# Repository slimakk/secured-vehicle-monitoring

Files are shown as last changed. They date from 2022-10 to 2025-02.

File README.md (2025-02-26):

# SECURED VEHICLE MONITORING USING OBDII AND LPWAN NETWORKS

This repository contains hardware design files and source code for bachelor thesis at FEEC BUT, which was sucessfully defended in 2023. The main goal behind the creation of this thesis was to create a device that would be capable of reporting important engine parameters to an external server for further processing.

[Link to a full thesis](https://www.vut.cz/studenti/zav-prace?zp_id=151037)
---------------------------------------------------------------------------
## Hardware specs
* MCU -- STM32 L431
* LPWAN module -- Quectel BG77, supports NB-IoT, LTE Cat M, GPS
* Power -- Synchronous Step-Down Converter by Texas Instruments
* Vehicle comms -- CAN Bus, K-Line, KWP2000
## Software
* OBD II support -- only mode 02
* Data transmission -- UDP, TCP, MQTT

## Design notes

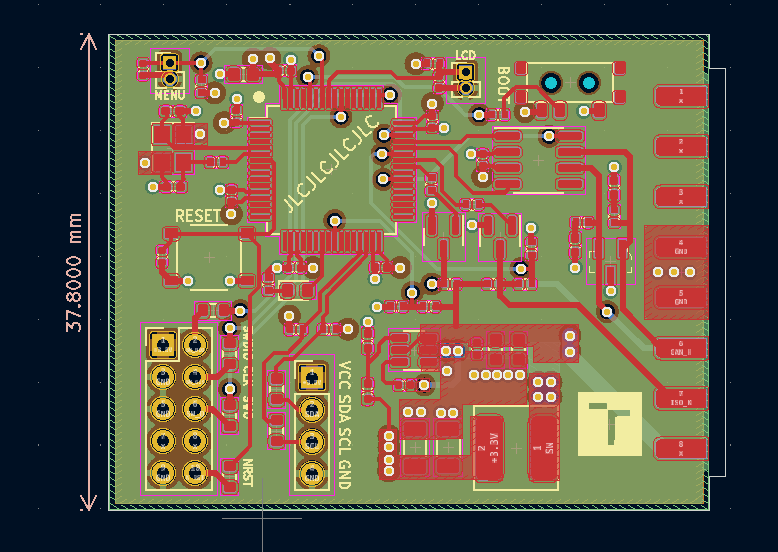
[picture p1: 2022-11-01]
Images/board.png

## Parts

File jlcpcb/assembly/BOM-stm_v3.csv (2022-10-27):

Comment | Designator | Footprint | LCSC
10k | R15,R4 | R_0402_1005Metric | C11616
SN65HVD231 | U2 | SOIC-8_3.9x4.9mm_P1.27mm | C129257
16 MHz | Y1 | Crystal_SMD_3225-4Pin_3.2x2.5mm | C13738
100n | C10,C11,C17,C2,C20,C21,C3,C4,C5,C6,C7 | C_0402_1005Metric | C1525
0R | R3 | R_0402_1005Metric | C17168
4u7 | C1 | C_0603_1608Metric | C19666
s8050 | Q1,Q2 | SOT-23 | C2146
22R | R10,R5,R6,R7,R8,R9 | R_0603_1608Metric | C23345
100R | R1,R2 | R_0402_1005Metric | C25076
510R | R16,R17 | R_0402_1005Metric | C25123
100k | R20,R22 | R_0402_1005Metric | C25741
27k | R21,R23 | R_0402_1005Metric | C25771
2k2 | R18,R19 | R_0402_1005Metric | C25879
4k7 | R11,R12,R24,R25 | R_0402_1005Metric | C25900
100n | C16 | C_0402_1005Metric | C307331
RST | SW1 | XKB_TS_1187A | C318884
BOOT0 | SW2 | XKB_SS-3292S | C397350
22u | C18,C19 | C_1206_3216Metric | C5672
LED | D2 | LED_0603_1608Metric | C72038
PESD2CAN_215 | D1 | SOT-23-3 | C75176
TPS562201 | U3 | SOT-23-6 | C90061
STM32L431RCTx | U1 | LQFP-64_10x10mm_P0.5mm | C92468
10u | C14,C15 | C_0603_1608Metric | C96446

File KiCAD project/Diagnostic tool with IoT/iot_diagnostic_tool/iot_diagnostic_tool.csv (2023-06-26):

Source: | C:\Users\miros\Desktop\bakalarka_latest\secured-vehicle-monitoring\KiCAD project\Diagnostic tool with IoT\iot_diagnostic_tool\iot_diagnostic_tool.kicad_sch
Date: | 5/17/2023 1:02:22 PM
Tool: | Eeschema (7.0.0)
Generator: | C:\Program Files\KiCad\6.0\bin\scripting\plugins/bom_csv_grouped_by_value_with_fp.py
Component Count: | 108
Ref | Qnty | Value | Cmp name | Footprint | Description | Vendor
AE1, | 1 | IoT_ANT | Antenna | Connector_Coaxial:U.FL_Hirose_U.FL-R-SMT-1_Vertical | Antenna
AE2, | 1 | GNSS_ANT | Antenna | Connector_Coaxial:U.FL_Hirose_U.FL-R-SMT-1_Vertical | Antenna
C1, | 1 | 4u7 | C | Capacitor_SMD:C_0603_1608Metric | Unpolarized capacitor
C2, C3, C4, C5, C6, C7, C8, C11, C14, C18, C23, C36, | 12 | 100n | C | Capacitor_SMD:C_0402_1005Metric | Unpolarized capacitor
C9, C10, | 2 | 8p | C | Capacitor_SMD:C_0402_1005Metric_Pad0.74x0.62mm_HandSolder | Unpolarized capacitor
C12, C13, | 2 | 10u | C | Capacitor_SMD:C_0603_1608Metric | Unpolarized capacitor
C15, C16, C17, | 3 | 22u | C | Capacitor_SMD:C_0805_2012Metric | Unpolarized capacitor
C19, C20, | 2 | 560p | C | Capacitor_SMD:C_0402_1005Metric_Pad0.74x0.62mm_HandSolder | Unpolarized capacitor
C21, | 1 | 10p | C | Capacitor_SMD:C_0402_1005Metric | Unpolarized capacitor
C22, | 1 | 33p | C | Capacitor_SMD:C_0402_1005Metric | Unpolarized capacitor
C24, | 1 | 100u | C_Polarized | Capacitor_Tantalum_SMD:CP_EIA-3528-21_Kemet-B | Polarized capacitor
C25, C37, | 2 | 10n | C | Capacitor_SMD:C_0402_1005Metric | Unpolarized capacitor
C27, C32, | 2 | 100n | C | Capacitor_SMD:C_0402_1005Metric_Pad0.74x0.62mm_HandSolder | Unpolarized capacitor
C28, C29, | 2 | 1u | C | Capacitor_SMD:C_0603_1608Metric | Unpolarized capacitor
C33, C34, C35, | 3 | 33p | C | Capacitor_SMD:C_0402_1005Metric_Pad0.74x0.62mm_HandSolder | Unpolarized capacitor
C38, C39, C40, C41, | 4 | NM | C | Capacitor_SMD:C_0402_1005Metric | Unpolarized capacitor
D1, | 1 | PESD2CAN | PESD2CAN | Package_TO_SOT_SMD:SOT-23 | SOT-23 Dual bidirectional TVS diode for CAN bus protection, 24V, 230W, Alternate KiCAD Library
D2, | 1 | LED | LED | Diode_SMD:D_0603_1608Metric | Light emitting diode
D5, | 1 | PESD5V0L5UY | PESD5V0L5UY | Package_TO_SOT_SMD:SOT-363_SC-70-6_Handsoldering | SOT-363 TVS Diode array, 5xUnidirectional, 5V, 25W, Alternate KiCAD Library
D6, D11, | 2 | TPSMF4L5.0A | TPSMF4L5.0A | Diode_SMD:D_SOD-123F | SOD-123F Unidirectional TVS diode, 5V, 400W, Alternate KiCAD Library
D7, | 1 | PESD5V0X1BT,215 | PESD5V2S2UT | Package_TO_SOT_SMD:SOT-23 | SOT-23 Dual Unidirectional TVS Diode, can be used as 1xBidirectional, 5.2V, 260W, Alternate KiCAD Library
D8, D9, D10, | 3 | ESD9L3.3 | ESD9L3.3 | Diode_SMD:D_SOD-923 | SOD-923 Unidirectional TVS diode, 3.3V, Alternate KiCAD Library
F1, | 1 | 2A | Fuse | Fuse:Fuse_0603_1608Metric_Pad1.05x0.95mm_HandSolder | Fuse
J2, | 1 | USB | Conn_02x04_Odd_Even | Connector_PinHeader_2.54mm:PinHeader_2x04_P2.54mm_Vertical_SMD | Generic connector, double row, 02x04, odd/even pin numbering scheme (row 1 odd numbers, row 2 even numbers), script generated (kicad-library-utils/schlib/autogen/connector/)
J3, | 1 | 693023010811 | 693023010811 | 693023010811:693023010811
J5, | 1 | Debug | Conn_02x05_Odd_Even | Connector_PinHeader_2.54mm:PinHeader_2x05_P2.54mm_Vertical | Generic connector, double row, 02x05, odd/even pin numbering scheme (row 1 odd numbers, row 2 even numbers), script generated (kicad-library-utils/schlib/autogen/connector/)
J6, | 1 | BOOT | Conn_01x03_Pin | Connector_PinHeader_2.54mm:PinHeader_1x03_P2.54mm_Vertical | Generic connector, single row, 01x03, script generated
J7, | 1 | OBD | 436500827 | 436500827:MOLEX_436500827
L1, | 1 | 3u3 | L | tme_library:VLS6045AF | Inductor
Q1, Q2, Q4, | 3 | BC817 | BC817 | Package_TO_SOT_SMD:SOT-23 | NPN SOT-23 transistor, 45V, 500mA, 250mW, Complementary to BC807, Alternate KiCAD Library
Q3, Q5, | 2 | BC817 | BC817 | Package_TO_SOT_SMD:SOT-23_Handsoldering | NPN SOT-23 transistor, 45V, 500mA, 250mW, Complementary to BC807, Alternate KiCAD Library
Q6, | 1 | RUM001L02T2CL | Q_NMOS_GSD | Package_TO_SOT_SMD:SOT-723 | N-MOSFET transistor, gate/source/drain
R1, R34, R37, | 3 | 10k | R | Resistor_SMD:R_0402_1005Metric | Resistor
R2, | 1 | 33k2 | R | Resistor_SMD:R_0402_1005Metric_Pad0.72x0.64mm_HandSolder | Resistor
R3, R40, R41, R44, R45, | 5 | 10k | R | Resistor_SMD:R_0402_1005Metric_Pad0.72x0.64mm_HandSolder | Resistor
R4, R5, | 2 | 100R | R | Resistor_SMD:R_0402_1005Metric | Resistor
R6, R8, R17, | 3 | 2k2 | R | Resistor_SMD:R_0402_1005Metric | Resistor
R7, R9, | 2 | 510R | R | Resistor_SMD:R_0402_1005Metric | Resistor
R10, R12, | 2 | 100k | R | Resistor_SMD:R_0402_1005Metric | Resistor
R11, R13, | 2 | 27k | R | Resistor_SMD:R_0402_1005Metric | Resistor
R14, R18, | 2 | 4k7 | R | Resistor_SMD:R_0402_1005Metric | Resistor
R15, R19, | 2 | 47k | R | Resistor_SMD:R_0402_1005Metric | Resistor
R16, | 1 | 200k | R | Resistor_SMD:R_0402_1005Metric_Pad0.72x0.64mm_HandSolder | Resistor
R28, R29, R30, R35, R36, R38, R39, | 7 | 0R | R | Resistor_SMD:R_0402_1005Metric | Resistor
R31, | 1 | 51k | R | Resistor_SMD:R_0402_1005Metric | Resistor
R32, | 1 | 15k | R | Resistor_SMD:R_0402_1005Metric | Resistor
R33, | 1 | 20k | R | Resistor_SMD:R_0402_1005Metric | Resistor
R42, R43, | 2 | 100k | R | Resistor_SMD:R_0402_1005Metric_Pad0.72x0.64mm_HandSolder | Resistor
SW1, | 1 | RST | SW_Push | tme_library:XKB_TS_1187A | Push button switch, generic, two pins
SW3, | 1 | IoT_RST | SW_Push | tme_library:XKB_TS_1187A | Push button switch, generic, two pins
U1, | 1 | STM32L431RCTx | STM32L431RCTx | Package_QFP:LQFP-64_10x10mm_P0.5mm | STMicroelectronics Arm Cortex-M4 MCU, 256KB flash, 64KB RAM, 80 MHz, 1.71-3.6V, 52 GPIO, LQFP64
U2, | 1 | TPS562201 | TPS562201 | Package_TO_SOT_SMD:SOT-23-6
U3, | 1 | SN65HVD231 | SN65HVD231 | Package_SO:SOIC-8_3.9x4.9mm_P1.27mm | CAN Bus Transceivers, 3.3V, 1Mbps,Ultra Low-Power capabilities, SOIC-8
U4, | 1 | BG77LA-64-SGNS | BG77LA-64-SGNS | BG77LA-64-SGNS:MODULE_BG77LA-64-SGNS
U6, | 1 | AP2120N-1.8 | AP2127N-1.8 | Package_TO_SOT_SMD:SOT-23_Handsoldering | 300mA low dropout linear regulator, shutdown pin, 2.5V-6V input voltage, 1.8V fixed positive output, SOT-23 package
U8, | 1 | NVT2010 | NVT2010 | Package_SO:TSSOP-24_4.4x7.8mm_P0.65mm | Bidirectional voltage-level translator for open-drain and push-pull applications
Y1, | 1 | 16 MHz | Crystal_GND24 | Crystal:Crystal_SMD_3225-4Pin_3.2x2.5mm | Four pin crystal, GND on pins 2 and 4

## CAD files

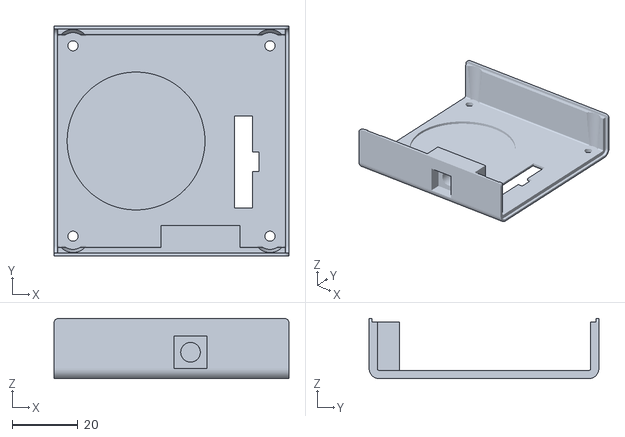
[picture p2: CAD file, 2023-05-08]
Case/IoT_OBD_tool/top.stl
71.6 x 70.0 x 18.3

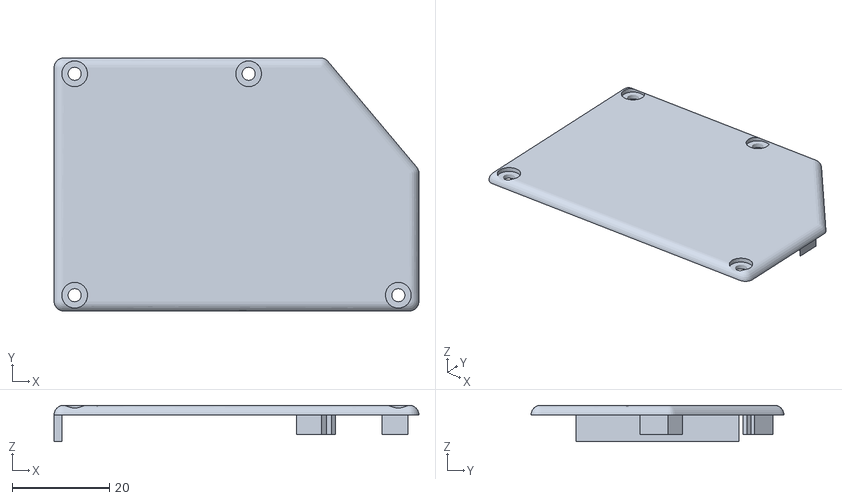
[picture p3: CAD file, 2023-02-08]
Case/OBD_tool/top_v2.stl
75.0 x 52.0 x 7.50

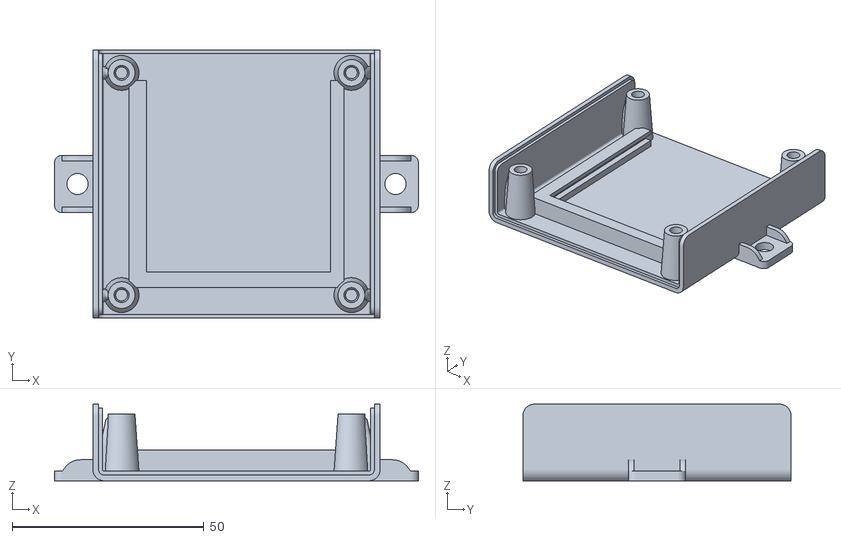
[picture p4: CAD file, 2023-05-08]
Case/IoT_OBD_tool/base.stl
95.0 x 70.0 x 20.0

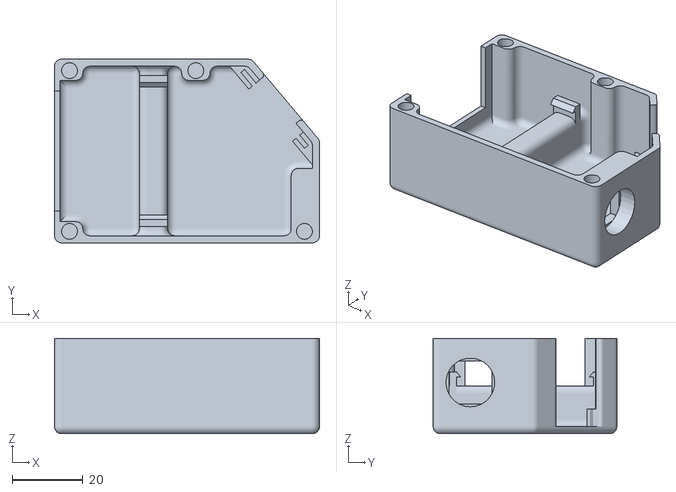
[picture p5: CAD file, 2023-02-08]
Case/OBD_tool/base_v2.stl
75.0 x 52.0 x 27.0

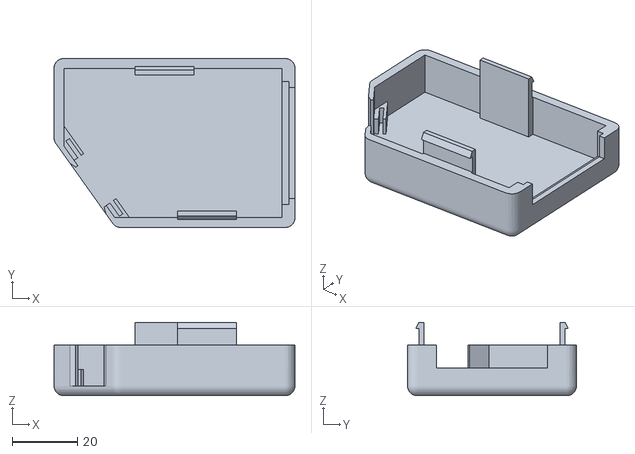
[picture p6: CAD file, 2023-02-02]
Case/OBD_tool/base_mir1.stl
73.9 x 51.8 x 22.5

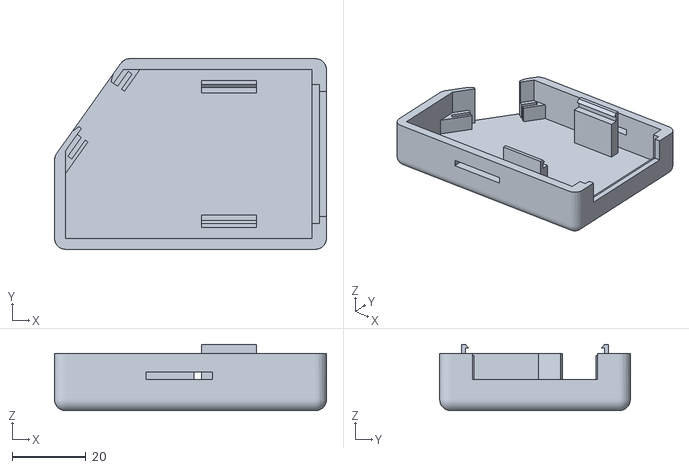
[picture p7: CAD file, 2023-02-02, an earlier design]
Case/OBD_tool/base.stl
73.9 x 51.8 x 18.0

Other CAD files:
Case/IoT_OBD_tool/base_v2.stl
Case/IoT_OBD_tool/base.ipt
Case/IoT_OBD_tool/case.iam
Case/IoT_OBD_tool/iot_diagnostic_tool.iam
Case/IoT_OBD_tool/iot_diagnostic_tool/436500827.iam
Case/IoT_OBD_tool/iot_diagnostic_tool/693023010811.iam
Case/IoT_OBD_tool/iot_diagnostic_tool/BG77LATEA-64-SGNS.iam
Case/IoT_OBD_tool/iot_diagnostic_tool/COMPOUND.ipt
Case/IoT_OBD_tool/iot_diagnostic_tool/COMPOUND_1.ipt
Case/IoT_OBD_tool/iot_diagnostic_tool/COMPOUND_2.ipt
Case/IoT_OBD_tool/iot_diagnostic_tool/COMPOUND_3.ipt
Case/IoT_OBD_tool/iot_diagnostic_tool/CP_EIA-3528-21_Kemet-B.iam
Case/IoT_OBD_tool/iot_diagnostic_tool/C_0402_1005Metric.iam
Case/IoT_OBD_tool/iot_diagnostic_tool/C_0603_1608Metric.iam
Case/IoT_OBD_tool/iot_diagnostic_tool/C_0805_2012Metric.iam
Case/IoT_OBD_tool/iot_diagnostic_tool/Crystal_SMD_3225-4Pin_3.2x2.5mm.iam
Case/IoT_OBD_tool/iot_diagnostic_tool/D_0603_1608Metric.iam
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

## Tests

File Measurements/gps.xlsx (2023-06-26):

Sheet: 2023-06-09_14_13_influxdb_data
Column6 | Column7 | Column8
false | false | true
dateTime:RFC3339 | double | string
_time | _value | _field
2023-05-21T14:39:20Z | 4913.9652 | lat
2023-05-21T14:39:25Z | 4913.9652 | lat
2023-05-21T14:39:50Z | 4913.9652 | lat
2023-05-21T14:40:05Z | 4913.9635 | lat
2023-05-21T14:40:15Z | 4913.9636 | lat
2023-05-21T14:40:30Z | 4913.9636 | lat
2023-05-21T14:40:45Z | 4913.9636 | lat
2023-05-21T14:40:50Z | 4913.9556 | lat
2023-05-21T14:41:00Z | 4913.9556 | lat
2023-05-21T14:41:25Z | 4913.9593 | lat
2023-05-21T14:41:45Z | 4913.9627 | lat
2023-05-21T14:41:50Z | 4913.9627 | lat
2023-05-21T14:42:00Z | 4913.9611 | lat
2023-05-21T14:42:30Z | 4913.9608 | lat
2023-05-21T14:42:35Z | 4913.97 | lat
2023-05-21T14:42:45Z | 4913.9694 | lat
2023-05-21T14:42:55Z | 4913.9694 | lat
2023-05-21T14:43:05Z | 4913.9694 | lat
2023-05-21T14:43:15Z | 4913.9764 | lat
2023-05-21T14:43:25Z | 4913.9718 | lat
2023-05-21T14:43:40Z | 4913.9718 | lat
2023-05-21T14:44:00Z | 4913.9433 | lat
2023-05-21T14:44:10Z | 4913.9433 | lat
2023-05-21T14:44:30Z | 4913.9677 | lat
2023-05-21T14:44:35Z | 4913.9647 | lat
2023-05-21T14:44:45Z | 4913.9647 | lat
2023-05-21T14:45:00Z | 4913.9616 | lat
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

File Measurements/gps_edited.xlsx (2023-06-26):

Latitude | Longitude
49.23275333 | 16.570635
49.23275333 | 16.570635
49.23275333 | 16.570635
49.232725 | 16.570595
49.23272667 | 16.570595
49.23272667 | 16.570595
49.23272667 | 16.570595
49.23259333 | 16.57066667
49.23259333 | 16.570665
49.232655 | 16.57063167
49.23271167 | 16.57059
49.23271167 | 16.57059
49.232685 | 16.57061333
49.23268 | 16.57061667
49.23283333 | 16.57067167
49.23282333 | 16.57067167
49.23282333 | 16.57067167
49.23282333 | 16.57067167
49.23294 | 16.57073667
49.23286333 | 16.570685
49.23286333 | 16.570685
49.23238833 | 16.57040167
49.23238833 | 16.57040167
49.232795 | 16.57070167
49.232745 | 16.57067
49.232745 | 16.57067
49.23269333 | 16.57045333
49.232615 | 16.57048667
49.232615 | 16.57048667
49.23268833 | 16.570675
49.23271833 | 16.57067
49.23268917 | 16.57066083
49.23268833 | 16.57064167
49.23268833 | 16.57064167
49.23264167 | 16.57032833
49.23268167 | 16.57033167
49.23268167 | 16.57033167
49.23268167 | 16.57033167
49.23268167 | 16.57033167
49.23160167 | 16.57167
49.23153167 | 16.5716
49.23153167 | 16.5716
49.22858833 | 16.57486167
49.22849333 | 16.57496
49.22932583 | 16.57639333
49.23015833 | 16.57782667
49.23015833 | 16.57782667
49.23015833 | 16.57782667
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

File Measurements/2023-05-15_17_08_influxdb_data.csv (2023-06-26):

#group | false | false | true | true | false | false | true | true
#datatype | string | long | dateTime:RFC3339 | dateTime:RFC3339 | dateTime:RFC3339 | double | string | string
#default | mean
 | result | table | _start | _stop | _time | _value | _field | _measurement
 |  | 0 | 2023-05-15T14:07:51.298137827Z | 2023-05-15T15:07:51.298137827Z | 2023-05-15T14:16:50Z | 14 | 0x5 | OBD
 |  | 0 | 2023-05-15T14:07:51.298137827Z | 2023-05-15T15:07:51.298137827Z | 2023-05-15T14:17:00Z | 14 | 0x5 | OBD
 |  | 0 | 2023-05-15T14:07:51.298137827Z | 2023-05-15T15:07:51.298137827Z | 2023-05-15T14:17:10Z | 14 | 0x5 | OBD
 |  | 0 | 2023-05-15T14:07:51.298137827Z | 2023-05-15T15:07:51.298137827Z | 2023-05-15T14:17:20Z | 14 | 0x5 | OBD
 |  | 0 | 2023-05-15T14:07:51.298137827Z | 2023-05-15T15:07:51.298137827Z | 2023-05-15T14:17:30Z | 16 | 0x5 | OBD
 |  | 0 | 2023-05-15T14:07:51.298137827Z | 2023-05-15T15:07:51.298137827Z | 2023-05-15T14:17:40Z | 19 | 0x5 | OBD
 |  | 0 | 2023-05-15T14:07:51.298137827Z | 2023-05-15T15:07:51.298137827Z | 2023-05-15T14:17:50Z | 21 | 0x5 | OBD
 |  | 0 | 2023-05-15T14:07:51.298137827Z | 2023-05-15T15:07:51.298137827Z | 2023-05-15T14:18:00Z | 23 | 0x5 | OBD
 |  | 0 | 2023-05-15T14:07:51.298137827Z | 2023-05-15T15:07:51.298137827Z | 2023-05-15T14:18:10Z | 25 | 0x5 | OBD
 |  | 0 | 2023-05-15T14:07:51.298137827Z | 2023-05-15T15:07:51.298137827Z | 2023-05-15T14:18:20Z | 26.5 | 0x5 | OBD
 |  | 0 | 2023-05-15T14:07:51.298137827Z | 2023-05-15T15:07:51.298137827Z | 2023-05-15T14:18:30Z | 28.5 | 0x5 | OBD
 |  | 0 | 2023-05-15T14:07:51.298137827Z | 2023-05-15T15:07:51.298137827Z | 2023-05-15T14:18:40Z | 30 | 0x5 | OBD
 |  | 0 | 2023-05-15T14:07:51.298137827Z | 2023-05-15T15:07:51.298137827Z | 2023-05-15T14:18:50Z | 31.5 | 0x5 | OBD
 |  | 0 | 2023-05-15T14:07:51.298137827Z | 2023-05-15T15:07:51.298137827Z | 2023-05-15T14:19:00Z | 33.5 | 0x5 | OBD
 |  | 0 | 2023-05-15T14:07:51.298137827Z | 2023-05-15T15:07:51.298137827Z | 2023-05-15T14:19:10Z | 35 | 0x5 | OBD
 |  | 0 | 2023-05-15T14:07:51.298137827Z | 2023-05-15T15:07:51.298137827Z | 2023-05-15T14:19:20Z | 36 | 0x5 | OBD
 |  | 0 | 2023-05-15T14:07:51.298137827Z | 2023-05-15T15:07:51.298137827Z | 2023-05-15T14:19:50Z | 38 | 0x5 | OBD
 |  | 0 | 2023-05-15T14:07:51.298137827Z | 2023-05-15T15:07:51.298137827Z | 2023-05-15T14:20:00Z | 40.5 | 0x5 | OBD
 |  | 0 | 2023-05-15T14:07:51.298137827Z | 2023-05-15T15:07:51.298137827Z | 2023-05-15T14:20:50Z | 44.25 | 0x5 | OBD
 |  | 0 | 2023-05-15T14:07:51.298137827Z | 2023-05-15T15:07:51.298137827Z | 2023-05-15T14:21:00Z | 47 | 0x5 | OBD
 |  | 0 | 2023-05-15T14:07:51.298137827Z | 2023-05-15T15:07:51.298137827Z | 2023-05-15T14:21:10Z | 47.5 | 0x5 | OBD
 |  | 0 | 2023-05-15T14:07:51.298137827Z | 2023-05-15T15:07:51.298137827Z | 2023-05-15T14:21:20Z | 48 | 0x5 | OBD
 |  | 0 | 2023-05-15T14:07:51.298137827Z | 2023-05-15T15:07:51.298137827Z | 2023-05-15T14:21:30Z | 49.5 | 0x5 | OBD
 |  | 0 | 2023-05-15T14:07:51.298137827Z | 2023-05-15T15:07:51.298137827Z | 2023-05-15T14:21:40Z | 50.5 | 0x5 | OBD
 |  | 0 | 2023-05-15T14:07:51.298137827Z | 2023-05-15T15:07:51.298137827Z | 2023-05-15T14:22:00Z | 52.5 | 0x5 | OBD
 |  | 0 | 2023-05-15T14:07:51.298137827Z | 2023-05-15T15:07:51.298137827Z | 2023-05-15T14:22:10Z | 56 | 0x5 | OBD
 |  | 0 | 2023-05-15T14:07:51.298137827Z | 2023-05-15T15:07:51.298137827Z | 2023-05-15T14:22:20Z | 57.5 | 0x5 | OBD
 |  | 0 | 2023-05-15T14:07:51.298137827Z | 2023-05-15T15:07:51.298137827Z | 2023-05-15T14:22:30Z | 58 | 0x5 | OBD
 |  | 0 | 2023-05-15T14:07:51.298137827Z | 2023-05-15T15:07:51.298137827Z | 2023-05-15T14:22:40Z | 59.5 | 0x5 | OBD
 |  | 0 | 2023-05-15T14:07:51.298137827Z | 2023-05-15T15:07:51.298137827Z | 2023-05-15T14:22:50Z | 62 | 0x5 | OBD
 |  | 0 | 2023-05-15T14:07:51.298137827Z | 2023-05-15T15:07:51.298137827Z | 2023-05-15T14:23:00Z | 64 | 0x5 | OBD
 |  | 0 | 2023-05-15T14:07:51.298137827Z | 2023-05-15T15:07:51.298137827Z | 2023-05-15T14:23:10Z | 65.5 | 0x5 | OBD
 |  | 0 | 2023-05-15T14:07:51.298137827Z | 2023-05-15T15:07:51.298137827Z | 2023-05-15T14:23:20Z | 68 | 0x5 | OBD
 |  | 0 | 2023-05-15T14:07:51.298137827Z | 2023-05-15T15:07:51.298137827Z | 2023-05-15T14:23:30Z | 68 | 0x5 | OBD
 |  | 0 | 2023-05-15T14:07:51.298137827Z | 2023-05-15T15:07:51.298137827Z | 2023-05-15T14:23:40Z | 72 | 0x5 | OBD
 |  | 0 | 2023-05-15T14:07:51.298137827Z | 2023-05-15T15:07:51.298137827Z | 2023-05-15T14:24:00Z | 75.5 | 0x5 | OBD
 |  | 0 | 2023-05-15T14:07:51.298137827Z | 2023-05-15T15:07:51.298137827Z | 2023-05-15T14:24:10Z | 75 | 0x5 | OBD
 |  | 0 | 2023-05-15T14:07:51.298137827Z | 2023-05-15T15:07:51.298137827Z | 2023-05-15T14:24:20Z | 75 | 0x5 | OBD
 |  | 0 | 2023-05-15T14:07:51.298137827Z | 2023-05-15T15:07:51.298137827Z | 2023-05-15T14:24:30Z | 76 | 0x5 | OBD
 |  | 0 | 2023-05-15T14:07:51.298137827Z | 2023-05-15T15:07:51.298137827Z | 2023-05-15T14:24:40Z | 77 | 0x5 | OBD
 |  | 0 | 2023-05-15T14:07:51.298137827Z | 2023-05-15T15:07:51.298137827Z | 2023-05-15T14:25:10Z | 80 | 0x5 | OBD
 |  | 0 | 2023-05-15T14:07:51.298137827Z | 2023-05-15T15:07:51.298137827Z | 2023-05-15T14:25:20Z | 89 | 0x5 | OBD
 |  | 0 | 2023-05-15T14:07:51.298137827Z | 2023-05-15T15:07:51.298137827Z | 2023-05-15T14:25:30Z | 92 | 0x5 | OBD
 |  | 0 | 2023-05-15T14:07:51.298137827Z | 2023-05-15T15:07:51.298137827Z | 2023-05-15T14:25:40Z | 94 | 0x5 | OBD
 |  | 0 | 2023-05-15T14:07:51.298137827Z | 2023-05-15T15:07:51.298137827Z | 2023-05-15T14:26:00Z | 87 | 0x5 | OBD
 |  | 0 | 2023-05-15T14:07:51.298137827Z | 2023-05-15T15:07:51.298137827Z | 2023-05-15T14:26:10Z | 88 | 0x5 | OBD
 |  | 0 | 2023-05-15T14:07:51.298137827Z | 2023-05-15T15:07:51.298137827Z | 2023-05-15T14:26:20Z | 85 | 0x5 | OBD
 |  | 0 | 2023-05-15T14:07:51.298137827Z | 2023-05-15T15:07:51.298137827Z | 2023-05-15T14:26:40Z | 88.66666666666667 | 0x5 | OBD
 |  | 0 | 2023-05-15T14:07:51.298137827Z | 2023-05-15T15:07:51.298137827Z | 2023-05-15T14:27:00Z | 84.5 | 0x5 | OBD
 |  | 0 | 2023-05-15T14:07:51.298137827Z | 2023-05-15T15:07:51.298137827Z | 2023-05-15T14:27:50Z | 85.8 | 0x5 | OBD
 |  | 0 | 2023-05-15T14:07:51.298137827Z | 2023-05-15T15:07:51.298137827Z | 2023-05-15T14:28:00Z | 86.5 | 0x5 | OBD
 |  | 0 | 2023-05-15T14:07:51.298137827Z | 2023-05-15T15:07:51.298137827Z | 2023-05-15T14:28:10Z | 88 | 0x5 | OBD
 |  | 0 | 2023-05-15T14:07:51.298137827Z | 2023-05-15T15:07:51.298137827Z | 2023-05-15T14:28:20Z | 89 | 0x5 | OBD
 |  | 0 | 2023-05-15T14:07:51.298137827Z | 2023-05-15T15:07:51.298137827Z | 2023-05-15T14:28:30Z | 87 | 0x5 | OBD
 |  | 0 | 2023-05-15T14:07:51.298137827Z | 2023-05-15T15:07:51.298137827Z | 2023-05-15T14:29:00Z | 87 | 0x5 | OBD
 |  | 0 | 2023-05-15T14:07:51.298137827Z | 2023-05-15T15:07:51.298137827Z | 2023-05-15T14:29:10Z | 88 | 0x5 | OBD
 |  | 0 | 2023-05-15T14:07:51.298137827Z | 2023-05-15T15:07:51.298137827Z | 2023-05-15T14:29:40Z | 88 | 0x5 | OBD
 |  | 0 | 2023-05-15T14:07:51.298137827Z | 2023-05-15T15:07:51.298137827Z | 2023-05-15T14:29:50Z | 88.5 | 0x5 | OBD
 |  | 0 | 2023-05-15T14:07:51.298137827Z | 2023-05-15T15:07:51.298137827Z | 2023-05-15T14:30:00Z | 87.5 | 0x5 | OBD
 |  | 0 | 2023-05-15T14:07:51.298137827Z | 2023-05-15T15:07:51.298137827Z | 2023-05-15T14:30:10Z | 88 | 0x5 | OBD
 |  | 0 | 2023-05-15T14:07:51.298137827Z | 2023-05-15T15:07:51.298137827Z | 2023-05-15T14:30:20Z | 89 | 0x5 | OBD
 |  | 0 | 2023-05-15T14:07:51.298137827Z | 2023-05-15T15:07:51.298137827Z | 2023-05-15T14:30:30Z | 89 | 0x5 | OBD
 |  | 0 | 2023-05-15T14:07:51.298137827Z | 2023-05-15T15:07:51.298137827Z | 2023-05-15T14:30:40Z | 87.5 | 0x5 | OBD
 |  | 0 | 2023-05-15T14:07:51.298137827Z | 2023-05-15T15:07:51.298137827Z | 2023-05-15T14:30:50Z | 87 | 0x5 | OBD
 |  | 0 | 2023-05-15T14:07:51.298137827Z | 2023-05-15T15:07:51.298137827Z | 2023-05-15T14:31:00Z | 87 | 0x5 | OBD
 |  | 0 | 2023-05-15T14:07:51.298137827Z | 2023-05-15T15:07:51.298137827Z | 2023-05-15T14:31:10Z | 87 | 0x5 | OBD
 |  | 0 | 2023-05-15T14:07:51.298137827Z | 2023-05-15T15:07:51.298137827Z | 2023-05-15T14:31:20Z | 88.5 | 0x5 | OBD
 |  | 0 | 2023-05-15T14:07:51.298137827Z | 2023-05-15T15:07:51.298137827Z | 2023-05-15T14:31:30Z | 90 | 0x5 | OBD
 |  | 0 | 2023-05-15T14:07:51.298137827Z | 2023-05-15T15:07:51.298137827Z | 2023-05-15T14:31:40Z | 88 | 0x5 | OBD
 |  | 0 | 2023-05-15T14:07:51.298137827Z | 2023-05-15T15:07:51.298137827Z | 2023-05-15T14:32:00Z | 88 | 0x5 | OBD
 |  | 0 | 2023-05-15T14:07:51.298137827Z | 2023-05-15T15:07:51.298137827Z | 2023-05-15T14:32:10Z | 89 | 0x5 | OBD
 |  | 0 | 2023-05-15T14:07:51.298137827Z | 2023-05-15T15:07:51.298137827Z | 2023-05-15T14:32:20Z | 90 | 0x5 | OBD
 |  | 0 | 2023-05-15T14:07:51.298137827Z | 2023-05-15T15:07:51.298137827Z | 2023-05-15T14:32:30Z | 87.5 | 0x5 | OBD
 |  | 0 | 2023-05-15T14:07:51.298137827Z | 2023-05-15T15:07:51.298137827Z | 2023-05-15T14:32:40Z | 87 | 0x5 | OBD
 |  | 0 | 2023-05-15T14:07:51.298137827Z | 2023-05-15T15:07:51.298137827Z | 2023-05-15T14:32:50Z | 87 | 0x5 | OBD
 |  | 0 | 2023-05-15T14:07:51.298137827Z | 2023-05-15T15:07:51.298137827Z | 2023-05-15T14:33:00Z | 87 | 0x5 | OBD
 |  | 0 | 2023-05-15T14:07:51.298137827Z | 2023-05-15T15:07:51.298137827Z | 2023-05-15T14:33:10Z | 88 | 0x5 | OBD
 |  | 0 | 2023-05-15T14:07:51.298137827Z | 2023-05-15T15:07:51.298137827Z | 2023-05-15T14:33:20Z | 86.5 | 0x5 | OBD
 |  | 0 | 2023-05-15T14:07:51.298137827Z | 2023-05-15T15:07:51.298137827Z | 2023-05-15T14:33:40Z | 86.5 | 0x5 | OBD
 |  | 0 | 2023-05-15T14:07:51.298137827Z | 2023-05-15T15:07:51.298137827Z | 2023-05-15T14:34:00Z | 87.5 | 0x5 | OBD
 |  | 0 | 2023-05-15T14:07:51.298137827Z | 2023-05-15T15:07:51.298137827Z | 2023-05-15T14:34:10Z | 87.25 | 0x5 | OBD
 |  | 0 | 2023-05-15T14:07:51.298137827Z | 2023-05-15T15:07:51.298137827Z | 2023-05-15T14:34:20Z | 87 | 0x5 | OBD
 |  | 0 | 2023-05-15T14:07:51.298137827Z | 2023-05-15T15:07:51.298137827Z | 2023-05-15T14:34:30Z | 87 | 0x5 | OBD
 |  | 0 | 2023-05-15T14:07:51.298137827Z | 2023-05-15T15:07:51.298137827Z | 2023-05-15T14:34:40Z | 88 | 0x5 | OBD
 |  | 0 | 2023-05-15T14:07:51.298137827Z | 2023-05-15T15:07:51.298137827Z | 2023-05-15T14:34:50Z | 87 | 0x5 | OBD
 |  | 0 | 2023-05-15T14:07:51.298137827Z | 2023-05-15T15:07:51.298137827Z | 2023-05-15T14:35:10Z | 87 | 0x5 | OBD
 |  | 0 | 2023-05-15T14:07:51.298137827Z | 2023-05-15T15:07:51.298137827Z | 2023-05-15T14:35:20Z | 87 | 0x5 | OBD
 |  | 0 | 2023-05-15T14:07:51.298137827Z | 2023-05-15T15:07:51.298137827Z | 2023-05-15T14:35:30Z | 88 | 0x5 | OBD
 |  | 0 | 2023-05-15T14:07:51.298137827Z | 2023-05-15T15:07:51.298137827Z | 2023-05-15T14:36:30Z | 87 | 0x5 | OBD
 |  | 0 | 2023-05-15T14:07:51.298137827Z | 2023-05-15T15:07:51.298137827Z | 2023-05-15T14:36:40Z | 86 | 0x5 | OBD
 |  | 0 | 2023-05-15T14:07:51.298137827Z | 2023-05-15T15:07:51.298137827Z | 2023-05-15T14:36:50Z | 87 | 0x5 | OBD
 |  | 0 | 2023-05-15T14:07:51.298137827Z | 2023-05-15T15:07:51.298137827Z | 2023-05-15T14:37:00Z | 90.5 | 0x5 | OBD
 |  | 0 | 2023-05-15T14:07:51.298137827Z | 2023-05-15T15:07:51.298137827Z | 2023-05-15T14:37:10Z | 88 | 0x5 | OBD
 |  | 0 | 2023-05-15T14:07:51.298137827Z | 2023-05-15T15:07:51.298137827Z | 2023-05-15T14:37:20Z | 90 | 0x5 | OBD
 |  | 0 | 2023-05-15T14:07:51.298137827Z | 2023-05-15T15:07:51.298137827Z | 2023-05-15T14:37:30Z | 88 | 0x5 | OBD
 |  | 0 | 2023-05-15T14:07:51.298137827Z | 2023-05-15T15:07:51.298137827Z | 2023-05-15T14:37:50Z | 86 | 0x5 | OBD
 |  | 0 | 2023-05-15T14:07:51.298137827Z | 2023-05-15T15:07:51.298137827Z | 2023-05-15T14:38:00Z | 86.4 | 0x5 | OBD
 |  | 0 | 2023-05-15T14:07:51.298137827Z | 2023-05-15T15:07:51.298137827Z | 2023-05-15T14:38:10Z | 87 | 0x5 | OBD
 |  | 0 | 2023-05-15T14:07:51.298137827Z | 2023-05-15T15:07:51.298137827Z | 2023-05-15T14:38:20Z | 87.5 | 0x5 | OBD
 |  | 0 | 2023-05-15T14:07:51.298137827Z | 2023-05-15T15:07:51.298137827Z | 2023-05-15T14:38:30Z | 86 | 0x5 | OBD
 |  | 0 | 2023-05-15T14:07:51.298137827Z | 2023-05-15T15:07:51.298137827Z | 2023-05-15T14:38:40Z | 86 | 0x5 | OBD
 |  | 0 | 2023-05-15T14:07:51.298137827Z | 2023-05-15T15:07:51.298137827Z | 2023-05-15T14:38:50Z | 87.5 | 0x5 | OBD
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

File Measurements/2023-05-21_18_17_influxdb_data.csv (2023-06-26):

#group | false | false | true | true | false | false | true | true
#datatype | string | long | dateTime:RFC3339 | dateTime:RFC3339 | dateTime:RFC3339 | double | string | string
#default | mean
 | result | table | _start | _stop | _time | _value | _field | _measurement
 |  | 0 | 2023-05-21T13:17:46.894135937Z | 2023-05-21T16:17:46.894135937Z | 2023-05-21T14:40:00Z | 4913.9652 | lat | location
 |  | 0 | 2023-05-21T13:17:46.894135937Z | 2023-05-21T16:17:46.894135937Z | 2023-05-21T14:41:00Z | 4913.960916666667 | lat | location
 |  | 0 | 2023-05-21T13:17:46.894135937Z | 2023-05-21T16:17:46.894135937Z | 2023-05-21T14:42:00Z | 4913.961020000001 | lat | location
 |  | 0 | 2023-05-21T13:17:46.894135937Z | 2023-05-21T16:17:46.894135937Z | 2023-05-21T14:43:00Z | 4913.96608 | lat | location
 |  | 0 | 2023-05-21T13:17:46.894135937Z | 2023-05-21T16:17:46.894135937Z | 2023-05-21T14:44:00Z | 4913.966539999999 | lat | location
 |  | 0 | 2023-05-21T13:17:46.894135937Z | 2023-05-21T16:17:46.894135937Z | 2023-05-21T14:45:00Z | 4913.9604 | lat | location
 |  | 0 | 2023-05-21T13:17:46.894135937Z | 2023-05-21T16:17:46.894135937Z | 2023-05-21T14:46:00Z | 4913.96015 | lat | location
 |  | 0 | 2023-05-21T13:17:46.894135937Z | 2023-05-21T16:17:46.894135937Z | 2023-05-21T14:47:00Z | 4913.960499999999 | lat | location
 |  | 0 | 2023-05-21T13:17:46.894135937Z | 2023-05-21T16:17:46.894135937Z | 2023-05-21T14:48:00Z | 4913.934139999999 | lat | location
 |  | 0 | 2023-05-21T13:17:46.894135937Z | 2023-05-21T16:17:46.894135937Z | 2023-05-21T14:49:00Z | 4913.772266666666 | lat | location
 |  | 0 | 2023-05-21T13:17:46.894135937Z | 2023-05-21T16:17:46.894135937Z | 2023-05-21T14:50:00Z | 4913.78952 | lat | location
 |  | 0 | 2023-05-21T13:17:46.894135937Z | 2023-05-21T16:17:46.894135937Z | 2023-05-21T14:51:00Z | 4913.8019 | lat | location
 |  | 0 | 2023-05-21T13:17:46.894135937Z | 2023-05-21T16:17:46.894135937Z | 2023-05-21T14:52:00Z | 4914.024633333334 | lat | location
 |  | 0 | 2023-05-21T13:17:46.894135937Z | 2023-05-21T16:17:46.894135937Z | 2023-05-21T14:53:00Z | 4914.43562 | lat | location
 |  | 0 | 2023-05-21T13:17:46.894135937Z | 2023-05-21T16:17:46.894135937Z | 2023-05-21T14:54:00Z | 4915.2221 | lat | location
 |  | 0 | 2023-05-21T13:17:46.894135937Z | 2023-05-21T16:17:46.894135937Z | 2023-05-21T14:55:00Z | 4915.596380000001 | lat | location
 |  | 0 | 2023-05-21T13:17:46.894135937Z | 2023-05-21T16:17:46.894135937Z | 2023-05-21T14:56:00Z | 4915.71915 | lat | location
 |  | 0 | 2023-05-21T13:17:46.894135937Z | 2023-05-21T16:17:46.894135937Z | 2023-05-21T14:57:00Z | 4915.751375 | lat | location
 |  | 0 | 2023-05-21T13:17:46.894135937Z | 2023-05-21T16:17:46.894135937Z | 2023-05-21T14:58:00Z | 4915.74848 | lat | location
 |  | 0 | 2023-05-21T13:17:46.894135937Z | 2023-05-21T16:17:46.894135937Z | 2023-05-21T14:59:00Z | 4915.7496833333325 | lat | location
 |  | 0 | 2023-05-21T13:17:46.894135937Z | 2023-05-21T16:17:46.894135937Z | 2023-05-21T15:00:00Z | 4915.74836 | lat | location
 |  | 0 | 2023-05-21T13:17:46.894135937Z | 2023-05-21T16:17:46.894135937Z | 2023-05-21T15:01:00Z | 4915.74388 | lat | location
 |  | 0 | 2023-05-21T13:17:46.894135937Z | 2023-05-21T16:17:46.894135937Z | 2023-05-21T15:02:00Z | 4915.74602 | lat | location
 |  | 0 | 2023-05-21T13:17:46.894135937Z | 2023-05-21T16:17:46.894135937Z | 2023-05-21T15:03:00Z | 4915.7496 | lat | location
 |  | 0 | 2023-05-21T13:17:46.894135937Z | 2023-05-21T16:17:46.894135937Z | 2023-05-21T15:04:00Z | 4915.75176 | lat | location
 |  | 0 | 2023-05-21T13:17:46.894135937Z | 2023-05-21T16:17:46.894135937Z | 2023-05-21T15:05:00Z | 4915.7483 | lat | location
 |  | 0 | 2023-05-21T13:17:46.894135937Z | 2023-05-21T16:17:46.894135937Z | 2023-05-21T15:06:00Z | 4915.67205 | lat | location
 |  | 0 | 2023-05-21T13:17:46.894135937Z | 2023-05-21T16:17:46.894135937Z | 2023-05-21T15:07:00Z | 4915.83746 | lat | location
 |  | 0 | 2023-05-21T13:17:46.894135937Z | 2023-05-21T16:17:46.894135937Z | 2023-05-21T15:08:00Z | 4916.2468 | lat | location
 |  | 0 | 2023-05-21T13:17:46.894135937Z | 2023-05-21T16:17:46.894135937Z | 2023-05-21T15:09:00Z | 4916.610216666667 | lat | location
 |  | 0 | 2023-05-21T13:17:46.894135937Z | 2023-05-21T16:17:46.894135937Z | 2023-05-21T15:10:00Z | 4917.035819999999 | lat | location
 |  | 0 | 2023-05-21T13:17:46.894135937Z | 2023-05-21T16:17:46.894135937Z | 2023-05-21T15:11:00Z | 4916.956975 | lat | location
 |  | 0 | 2023-05-21T13:17:46.894135937Z | 2023-05-21T16:17:46.894135937Z | 2023-05-21T15:12:00Z | 4915.951633333334 | lat | location
 |  | 0 | 2023-05-21T13:17:46.894135937Z | 2023-05-21T16:17:46.894135937Z | 2023-05-21T15:13:00Z | 4915.376649999999 | lat | location
 |  | 0 | 2023-05-21T13:17:46.894135937Z | 2023-05-21T16:17:46.894135937Z | 2023-05-21T15:14:00Z | 4914.728349999999 | lat | location
 |  | 0 | 2023-05-21T13:17:46.894135937Z | 2023-05-21T16:17:46.894135937Z | 2023-05-21T15:15:00Z | 4914.0658 | lat | location
 |  | 0 | 2023-05-21T13:17:46.894135937Z | 2023-05-21T16:17:46.894135937Z | 2023-05-21T15:16:00Z | 4913.71425 | lat | location
 |  | 0 | 2023-05-21T13:17:46.894135937Z | 2023-05-21T16:17:46.894135937Z | 2023-05-21T15:17:00Z | 4913.092825 | lat | location
 |  | 0 | 2023-05-21T13:17:46.894135937Z | 2023-05-21T16:17:46.894135937Z | 2023-05-21T15:18:00Z | 4912.761833333333 | lat | location
 |  | 0 | 2023-05-21T13:17:46.894135937Z | 2023-05-21T16:17:46.894135937Z | 2023-05-21T15:19:00Z | 4912.807916666668 | lat | location
 |  | 0 | 2023-05-21T13:17:46.894135937Z | 2023-05-21T16:17:46.894135937Z | 2023-05-21T15:20:00Z | 4913.063425 | lat | location
 |  | 0 | 2023-05-21T13:17:46.894135937Z | 2023-05-21T16:17:46.894135937Z | 2023-05-21T15:21:00Z | 4913.1784 | lat | location
 |  | 0 | 2023-05-21T13:17:46.894135937Z | 2023-05-21T16:17:46.894135937Z | 2023-05-21T15:22:00Z | 4913.50032 | lat | location
 |  | 0 | 2023-05-21T13:17:46.894135937Z | 2023-05-21T16:17:46.894135937Z | 2023-05-21T15:23:00Z | 4913.699439999999 | lat | location
 |  | 0 | 2023-05-21T13:17:46.894135937Z | 2023-05-21T16:17:46.894135937Z | 2023-05-21T15:24:00Z | 4913.6655833333325 | lat | location
 |  | 0 | 2023-05-21T13:17:46.894135937Z | 2023-05-21T16:17:46.894135937Z | 2023-05-21T15:25:00Z | 4913.55534 | lat | location
 |  | 0 | 2023-05-21T13:17:46.894135937Z | 2023-05-21T16:17:46.894135937Z | 2023-05-21T15:26:00Z | 4913.627433333332 | lat | location
 |  | 0 | 2023-05-21T13:17:46.894135937Z | 2023-05-21T16:17:46.894135937Z | 2023-05-21T15:27:00Z | 4913.6517 | lat | location
 |  | 0 | 2023-05-21T13:17:46.894135937Z | 2023-05-21T16:17:46.894135937Z | 2023-05-21T15:28:00Z | 4913.8866 | lat | location
 |  | 0 | 2023-05-21T13:17:46.894135937Z | 2023-05-21T16:17:46.894135937Z | 2023-05-21T15:29:00Z | 4914.210959999999 | lat | location
 |  | 0 | 2023-05-21T13:17:46.894135937Z | 2023-05-21T16:17:46.894135937Z | 2023-05-21T15:30:00Z | 4914.417225 | lat | location
 |  | 0 | 2023-05-21T13:17:46.894135937Z | 2023-05-21T16:17:46.894135937Z | 2023-05-21T15:31:00Z | 4914.71936 | lat | location
 |  | 0 | 2023-05-21T13:17:46.894135937Z | 2023-05-21T16:17:46.894135937Z | 2023-05-21T15:32:00Z | 4914.933383333333 | lat | location
 |  | 0 | 2023-05-21T13:17:46.894135937Z | 2023-05-21T16:17:46.894135937Z | 2023-05-21T15:33:00Z | 4915.1081 | lat | location
 |  | 0 | 2023-05-21T13:17:46.894135937Z | 2023-05-21T16:17:46.894135937Z | 2023-05-21T15:34:00Z | 4915.40674 | lat | location
 |  | 0 | 2023-05-21T13:17:46.894135937Z | 2023-05-21T16:17:46.894135937Z | 2023-05-21T15:35:00Z | 4915.60292 | lat | location
 |  | 0 | 2023-05-21T13:17:46.894135937Z | 2023-05-21T16:17:46.894135937Z | 2023-05-21T15:36:00Z | 4915.432133333333 | lat | location
 |  | 0 | 2023-05-21T13:17:46.894135937Z | 2023-05-21T16:17:46.894135937Z | 2023-05-21T15:37:00Z | 4915.270833333333 | lat | location
 |  | 0 | 2023-05-21T13:17:46.894135937Z | 2023-05-21T16:17:46.894135937Z | 2023-05-21T15:38:00Z | 4915.0987749999995 | lat | location
 |  | 0 | 2023-05-21T13:17:46.894135937Z | 2023-05-21T16:17:46.894135937Z | 2023-05-21T15:39:00Z | 4915.141699999999 | lat | location
 |  | 0 | 2023-05-21T13:17:46.894135937Z | 2023-05-21T16:17:46.894135937Z | 2023-05-21T15:40:00Z | 4915.2922499999995 | lat | location
 |  | 0 | 2023-05-21T13:17:46.894135937Z | 2023-05-21T16:17:46.894135937Z | 2023-05-21T15:41:00Z | 4915.29882 | lat | location
 |  | 0 | 2023-05-21T13:17:46.894135937Z | 2023-05-21T16:17:46.894135937Z | 2023-05-21T15:42:00Z | 4915.29905 | lat | location
 |  | 0 | 2023-05-21T13:17:46.894135937Z | 2023-05-21T16:17:46.894135937Z | 2023-05-21T15:43:00Z | 4915.295933333334 | lat | location
 |  | 0 | 2023-05-21T13:17:46.894135937Z | 2023-05-21T16:17:46.894135937Z | 2023-05-21T15:44:00Z | 4915.295625 | lat | location
 |  | 0 | 2023-05-21T13:17:46.894135937Z | 2023-05-21T16:17:46.894135937Z | 2023-05-21T15:45:00Z | 4915.2959 | lat | location
 |  | 0 | 2023-05-21T13:17:46.894135937Z | 2023-05-21T16:17:46.894135937Z | 2023-05-21T15:46:00Z | 4915.241075 | lat | location
 |  | 0 | 2023-05-21T13:17:46.894135937Z | 2023-05-21T16:17:46.894135937Z | 2023-05-21T15:47:00Z | 4915.1188 | lat | location
 |  | 0 | 2023-05-21T13:17:46.894135937Z | 2023-05-21T16:17:46.894135937Z | 2023-05-21T15:48:00Z | 4915.1678 | lat | location
 |  | 0 | 2023-05-21T13:17:46.894135937Z | 2023-05-21T16:17:46.894135937Z | 2023-05-21T15:49:00Z | 4915.306233333333 | lat | location
 |  | 0 | 2023-05-21T13:17:46.894135937Z | 2023-05-21T16:17:46.894135937Z | 2023-05-21T15:50:00Z | 4915.455733333333 | lat | location
 |  | 0 | 2023-05-21T13:17:46.894135937Z | 2023-05-21T16:17:46.894135937Z | 2023-05-21T15:51:00Z | 4915.56758 | lat | location
 |  | 0 | 2023-05-21T13:17:46.894135937Z | 2023-05-21T16:17:46.894135937Z | 2023-05-21T15:52:00Z | 4915.348 | lat | location
 |  | 0 | 2023-05-21T13:17:46.894135937Z | 2023-05-21T16:17:46.894135937Z | 2023-05-21T15:53:00Z | 4915.0854 | lat | location
 |  | 0 | 2023-05-21T13:17:46.894135937Z | 2023-05-21T16:17:46.894135937Z | 2023-05-21T15:54:00Z | 4914.858340000001 | lat | location
 |  | 0 | 2023-05-21T13:17:46.894135937Z | 2023-05-21T16:17:46.894135937Z | 2023-05-21T15:55:00Z | 4914.522733333333 | lat | location
 |  | 0 | 2023-05-21T13:17:46.894135937Z | 2023-05-21T16:17:46.894135937Z | 2023-05-21T15:56:00Z | 4914.113816666667 | lat | location
 |  | 0 | 2023-05-21T13:17:46.894135937Z | 2023-05-21T16:17:46.894135937Z | 2023-05-21T15:57:00Z | 4913.7683 | lat | location
 |  | 1 | 2023-05-21T13:17:46.894135937Z | 2023-05-21T16:17:46.894135937Z | 2023-05-21T14:40:00Z | 1634.2380999999998 | lon | location
 |  | 1 | 2023-05-21T13:17:46.894135937Z | 2023-05-21T16:17:46.894135937Z | 2023-05-21T14:41:00Z | 1634.2371166666665 | lon | location
 |  | 1 | 2023-05-21T13:17:46.894135937Z | 2023-05-21T16:17:46.894135937Z | 2023-05-21T14:42:00Z | 1634.2366799999998 | lon | location
 |  | 1 | 2023-05-21T13:17:46.894135937Z | 2023-05-21T16:17:46.894135937Z | 2023-05-21T14:43:00Z | 1634.2389799999996 | lon | location
 |  | 1 | 2023-05-21T13:17:46.894135937Z | 2023-05-21T16:17:46.894135937Z | 2023-05-21T14:44:00Z | 1634.23816 | lon | location
 |  | 1 | 2023-05-21T13:17:46.894135937Z | 2023-05-21T16:17:46.894135937Z | 2023-05-21T14:45:00Z | 1634.23476 | lon | location
 |  | 1 | 2023-05-21T13:17:46.894135937Z | 2023-05-21T16:17:46.894135937Z | 2023-05-21T14:46:00Z | 1634.2364 | lon | location
 |  | 1 | 2023-05-21T13:17:46.894135937Z | 2023-05-21T16:17:46.894135937Z | 2023-05-21T14:47:00Z | 1634.2291500000001 | lon | location
 |  | 1 | 2023-05-21T13:17:46.894135937Z | 2023-05-21T16:17:46.894135937Z | 2023-05-21T14:48:00Z | 1634.25118 | lon | location
 |  | 1 | 2023-05-21T13:17:46.894135937Z | 2023-05-21T16:17:46.894135937Z | 2023-05-21T14:49:00Z | 1634.4284333333333 | lon | location
 |  | 1 | 2023-05-21T13:17:46.894135937Z | 2023-05-21T16:17:46.894135937Z | 2023-05-21T14:50:00Z | 1634.6352000000002 | lon | location
 |  | 1 | 2023-05-21T13:17:46.894135937Z | 2023-05-21T16:17:46.894135937Z | 2023-05-21T14:51:00Z | 1634.8216 | lon | location
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

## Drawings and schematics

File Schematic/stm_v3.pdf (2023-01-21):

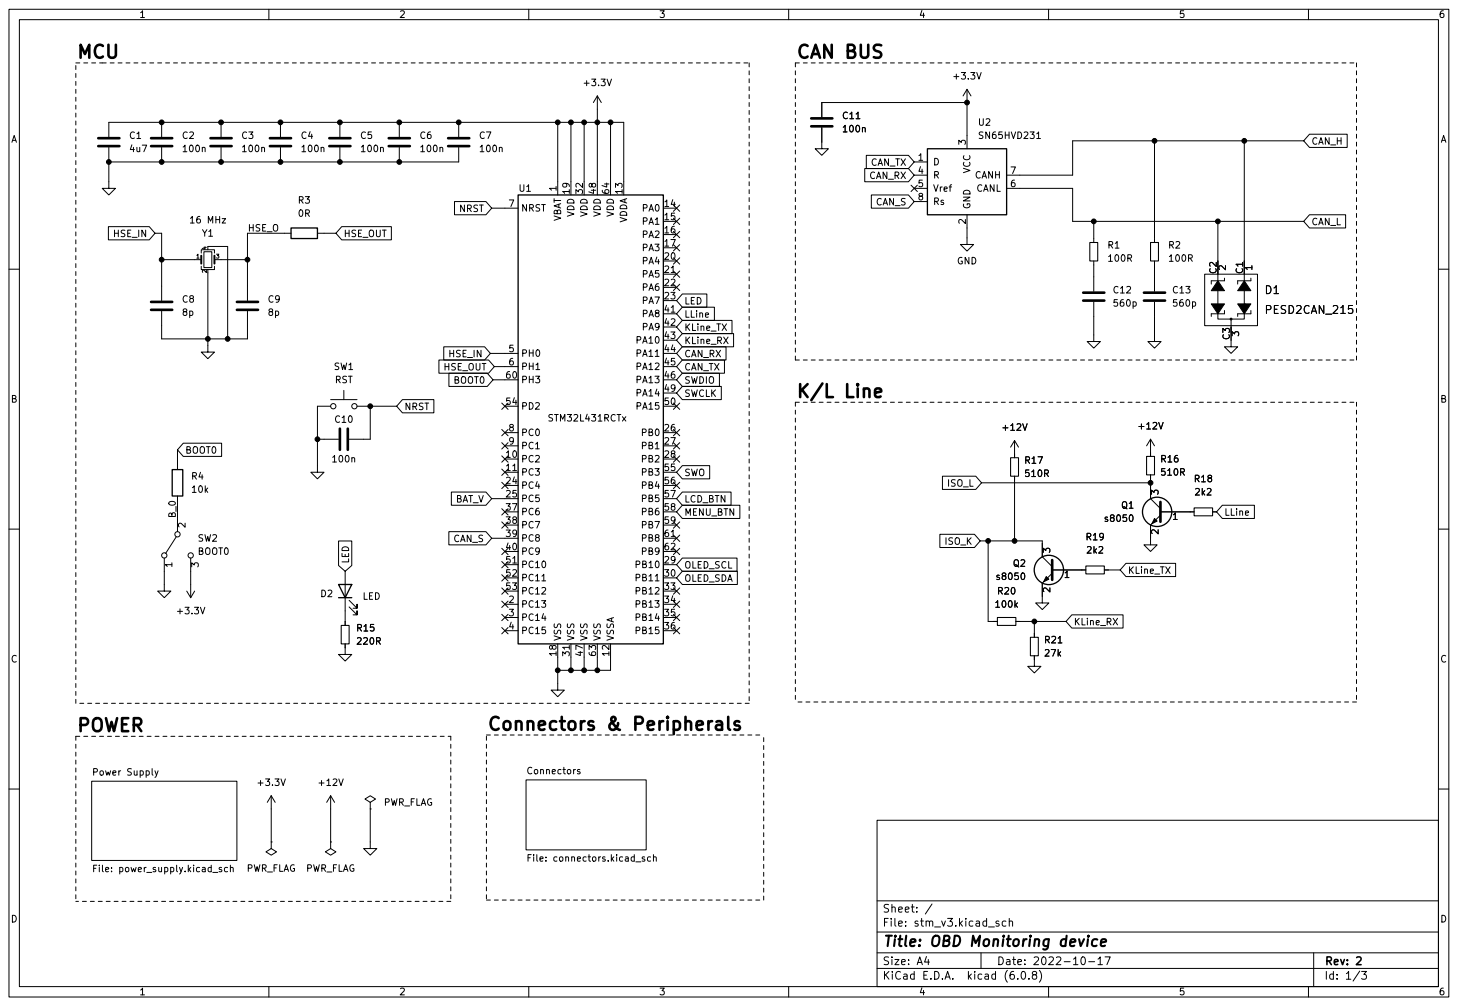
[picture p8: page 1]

1 PC2 10 PC3 11 VSSA 12 VDDA 13 PA0 14 PA1 15 PA2 16 PA3 17 VSS 18 VDD 19 PC13 2 PA4 20 PA5 21 PA6 22 PA7 23 PC4 24 PC5 25 PB0 26 PB1 27 PB2 28 PB10 29 PC14 3 PB11 30 VSS 31 VDD 32 PB12 33 PB13 34 PB14 35 PB15 36 PC6 37 PC7 38 PC8 39 PC15 4 PC9 40 PA8 41 PA9 42 PA10 43 PA11 44 PA12 45 PA13 46 VSS 47 VDD 48 PA14 49 PH0 5 PA15 50 PC10 51 PC11 52 PC12 53 PD2 54 PB3 55 PB4 56 PB5 57 PB6 58 PB7 59 PH1 6 PH3 60 PB8 61 PB9 62 VSS 63 VDD 64 NRST 7 PC0 8 PC1 9 U1 STM32L431RCTx C2

File: stm_v3.kicad_sch Sheet: / Connectors File: connectors.kicad_sch Power Supply

Id: 1/3 Title: OBD Monitoring device

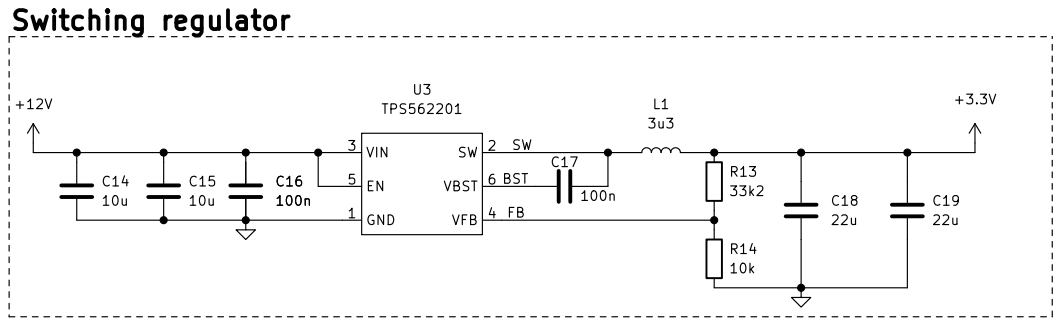
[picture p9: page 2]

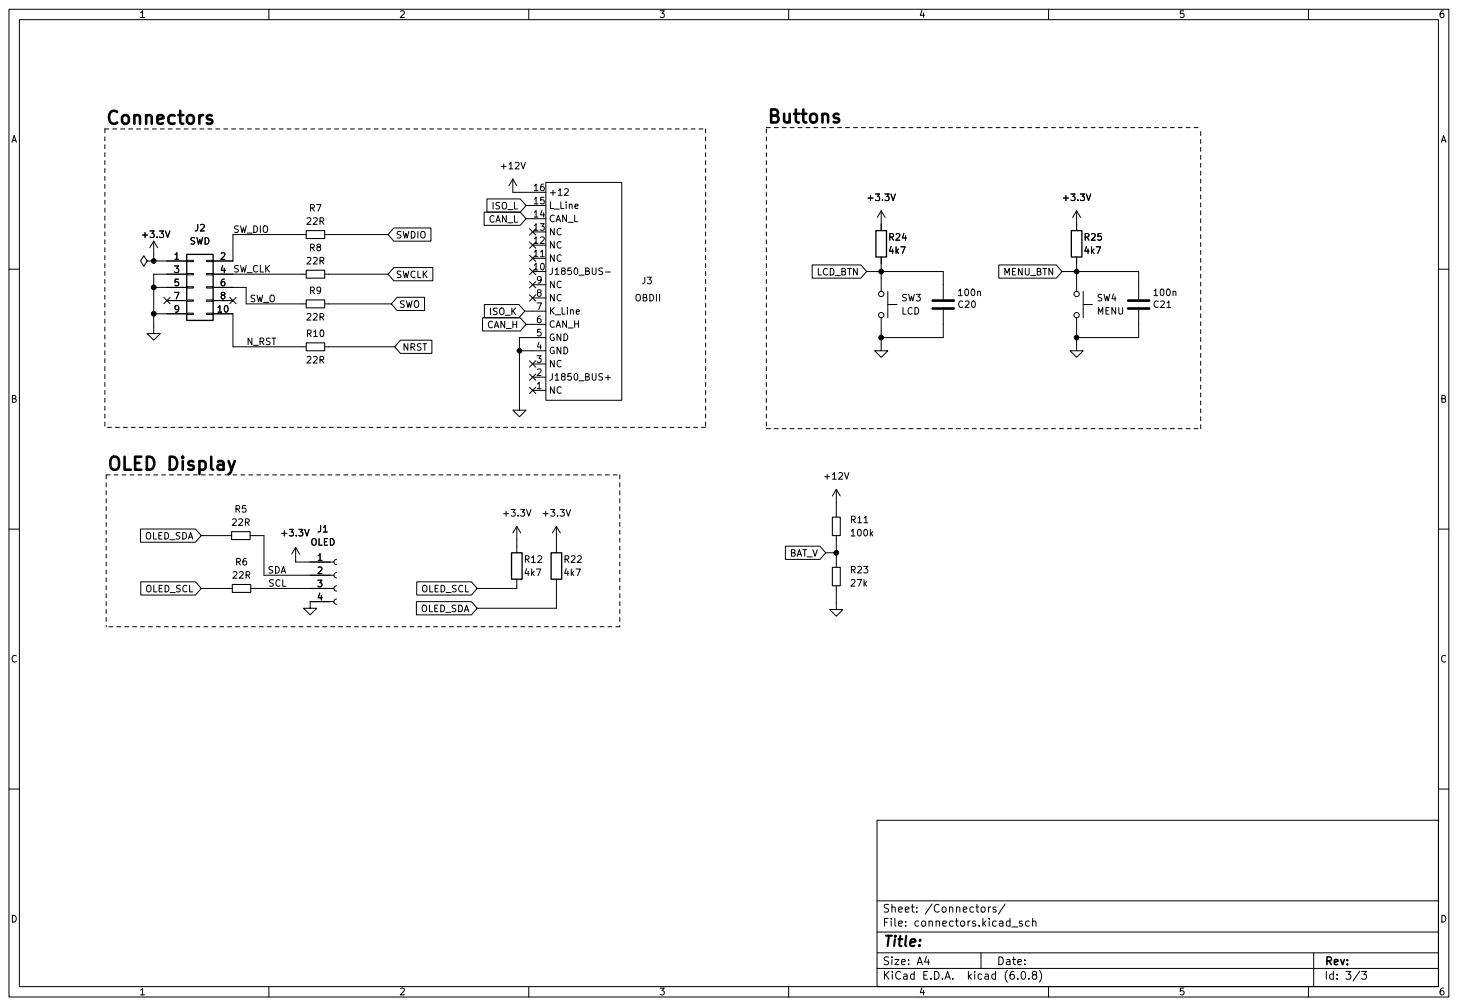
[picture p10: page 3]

5 5 | 6 6
7 7 9 | 8 8

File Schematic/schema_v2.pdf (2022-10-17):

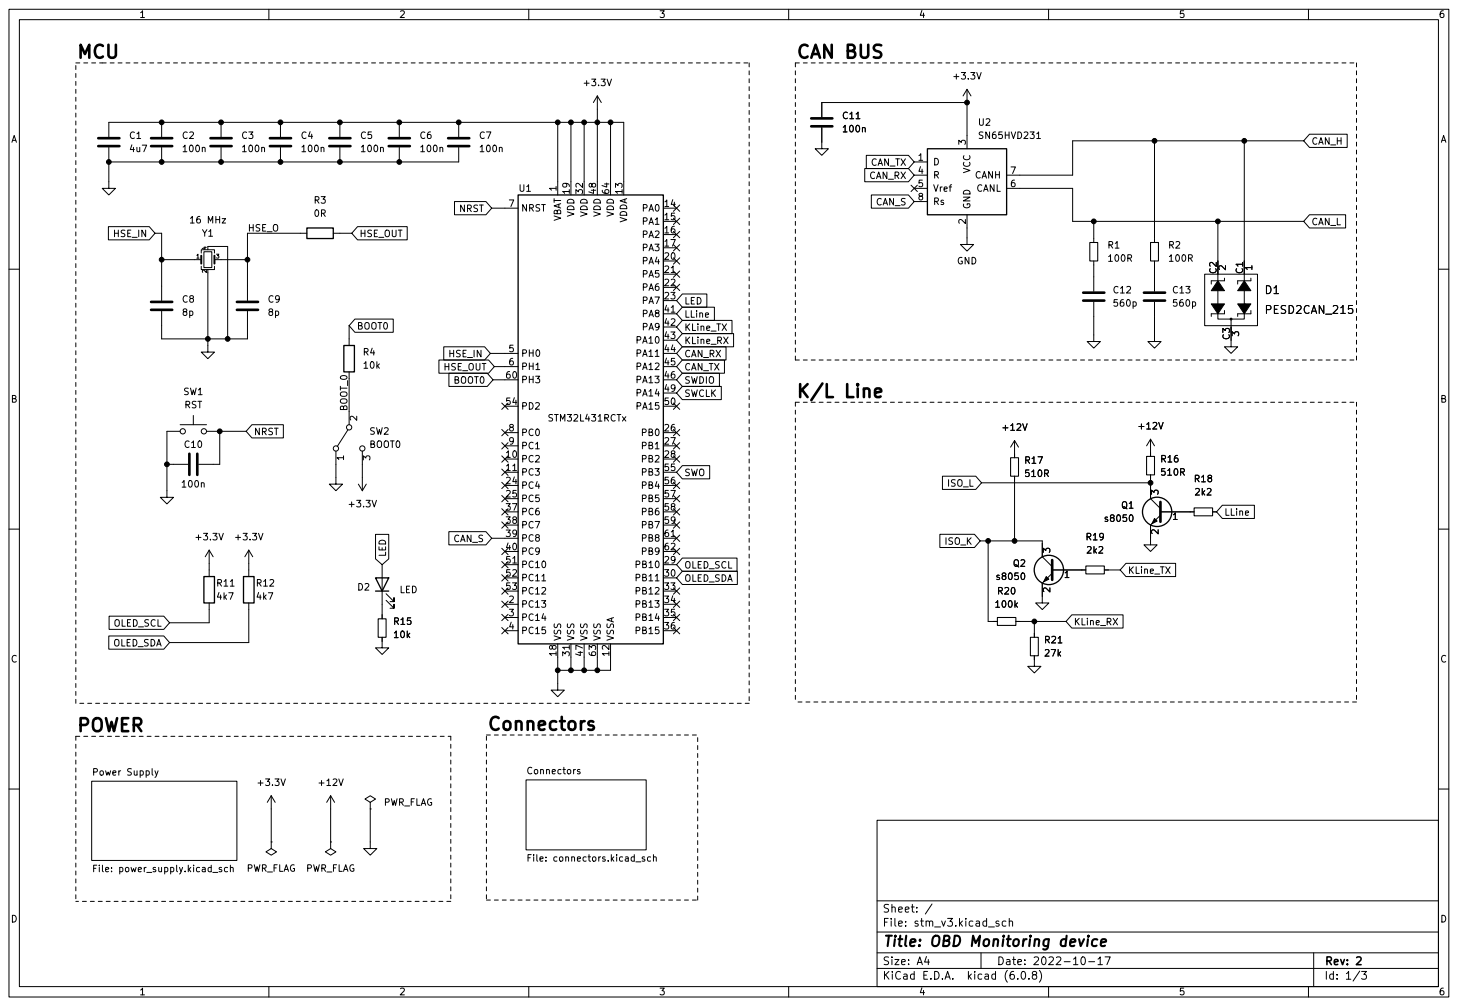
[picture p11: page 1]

1 PC2 10 PC3 11 VSSA 12 VDDA 13 PA0 14 PA1 15 PA2 16 PA3 17 VSS 18 VDD 19 PC13 2 PA4 20 PA5 21 PA6 22 PA7 23 PC4 24 PC5 25 PB0 26 PB1 27 PB2 28 PB10 29 PC14 3 PB11 30 VSS 31 VDD 32 PB12 33 PB13 34 PB14 35 PB15 36 PC6 37 PC7 38 PC8 39 PC15 4 PC9 40 PA8 41 PA9 42 PA10 43 PA11 44 PA12 45 PA13 46 VSS 47 VDD 48 PA14 49 PH0 5 PA15 50 PC10 51 PC11 52 PC12 53 PD2 54 PB3 55 PB4 56 PB5 57 PB6 58 PB7 59 PH1 6 PH3 60 PB8 61 PB9 62 VSS 63 VDD 64 NRST 7 PC0 8 PC1 9 U1 STM32L431RCTx +3.3V C11

File: stm_v3.kicad_sch Sheet: / Connectors File: connectors.kicad_sch Power Supply

Id: 1/3 Title: OBD Monitoring device


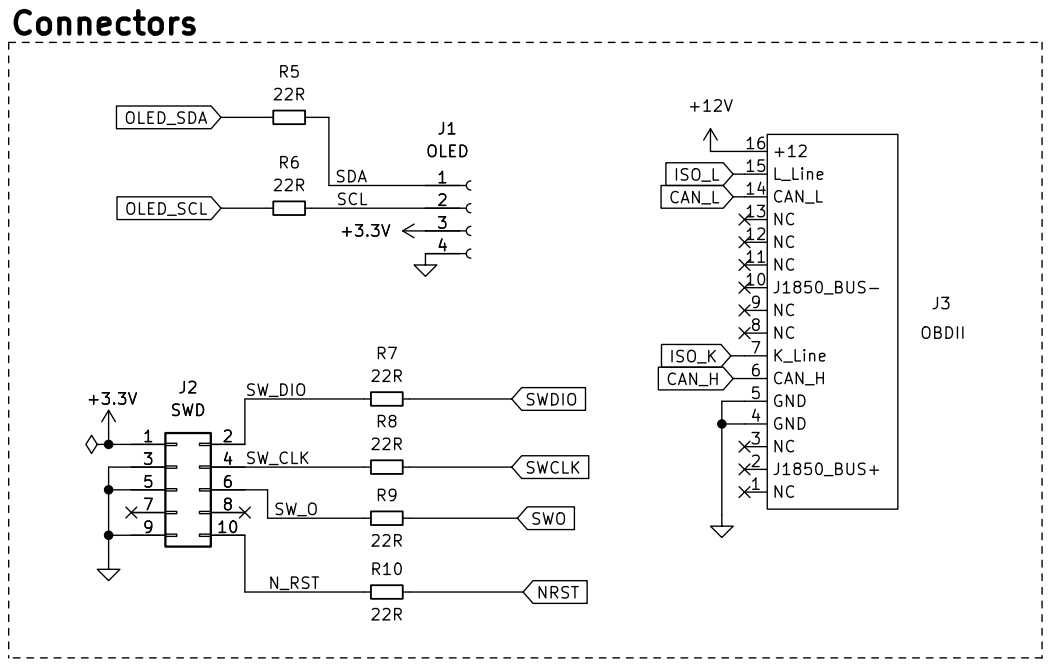
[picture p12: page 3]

File: connectors.kicad_sch Sheet: /Connectors/

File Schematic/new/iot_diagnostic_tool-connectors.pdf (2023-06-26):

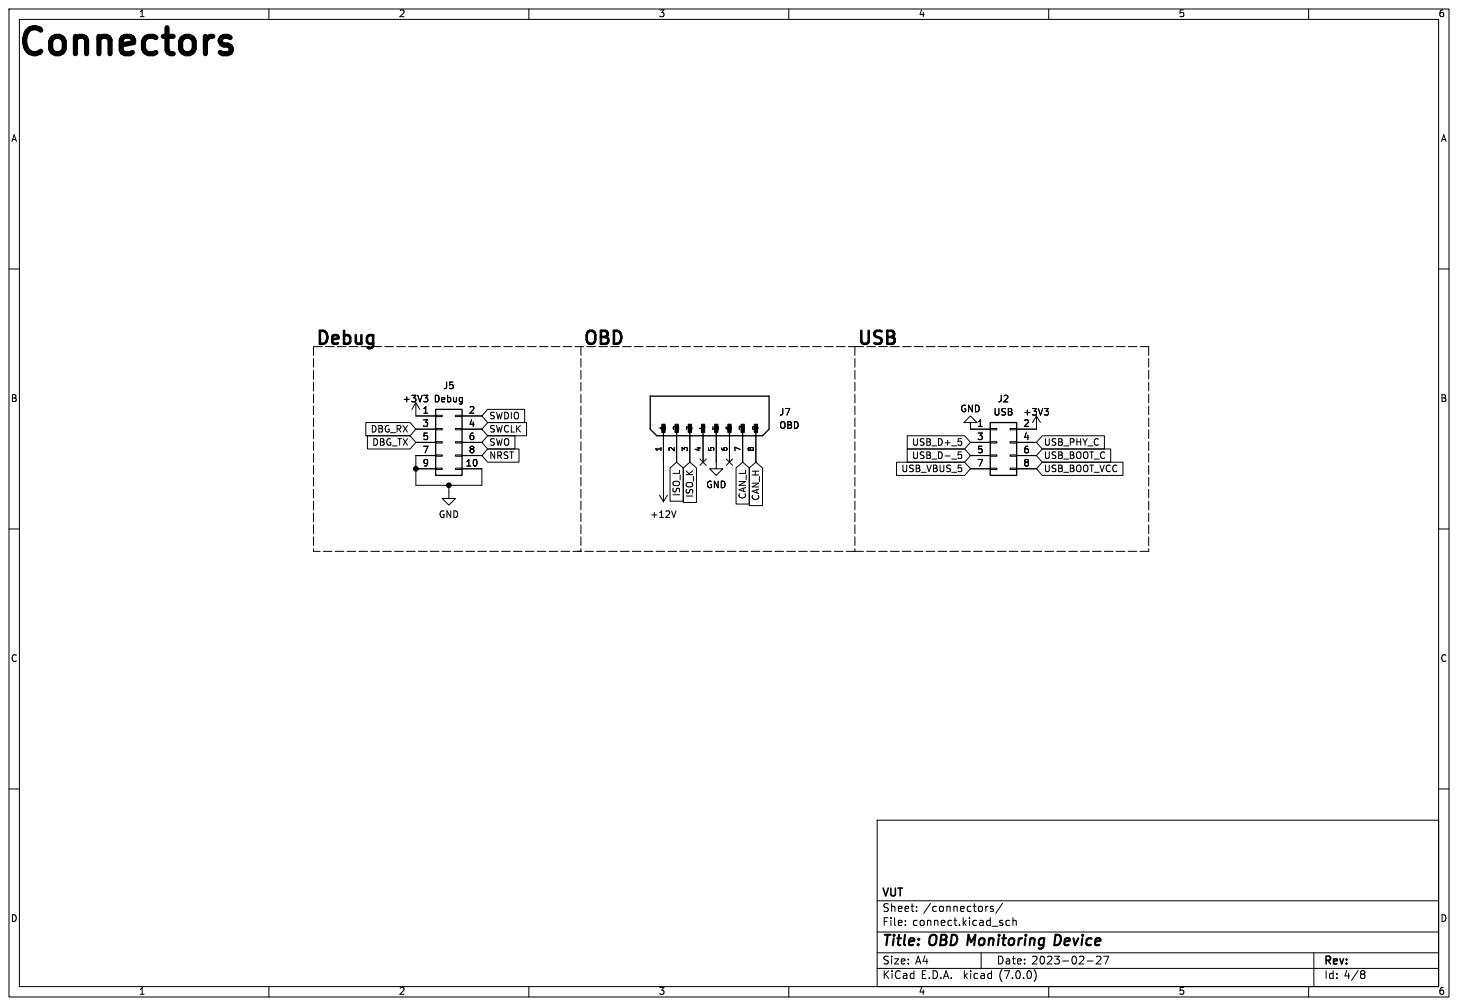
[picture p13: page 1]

File: connect.kicad_sch Sheet: /connectors/ VUT

Id: 4/8 Title: OBD Monitoring Device

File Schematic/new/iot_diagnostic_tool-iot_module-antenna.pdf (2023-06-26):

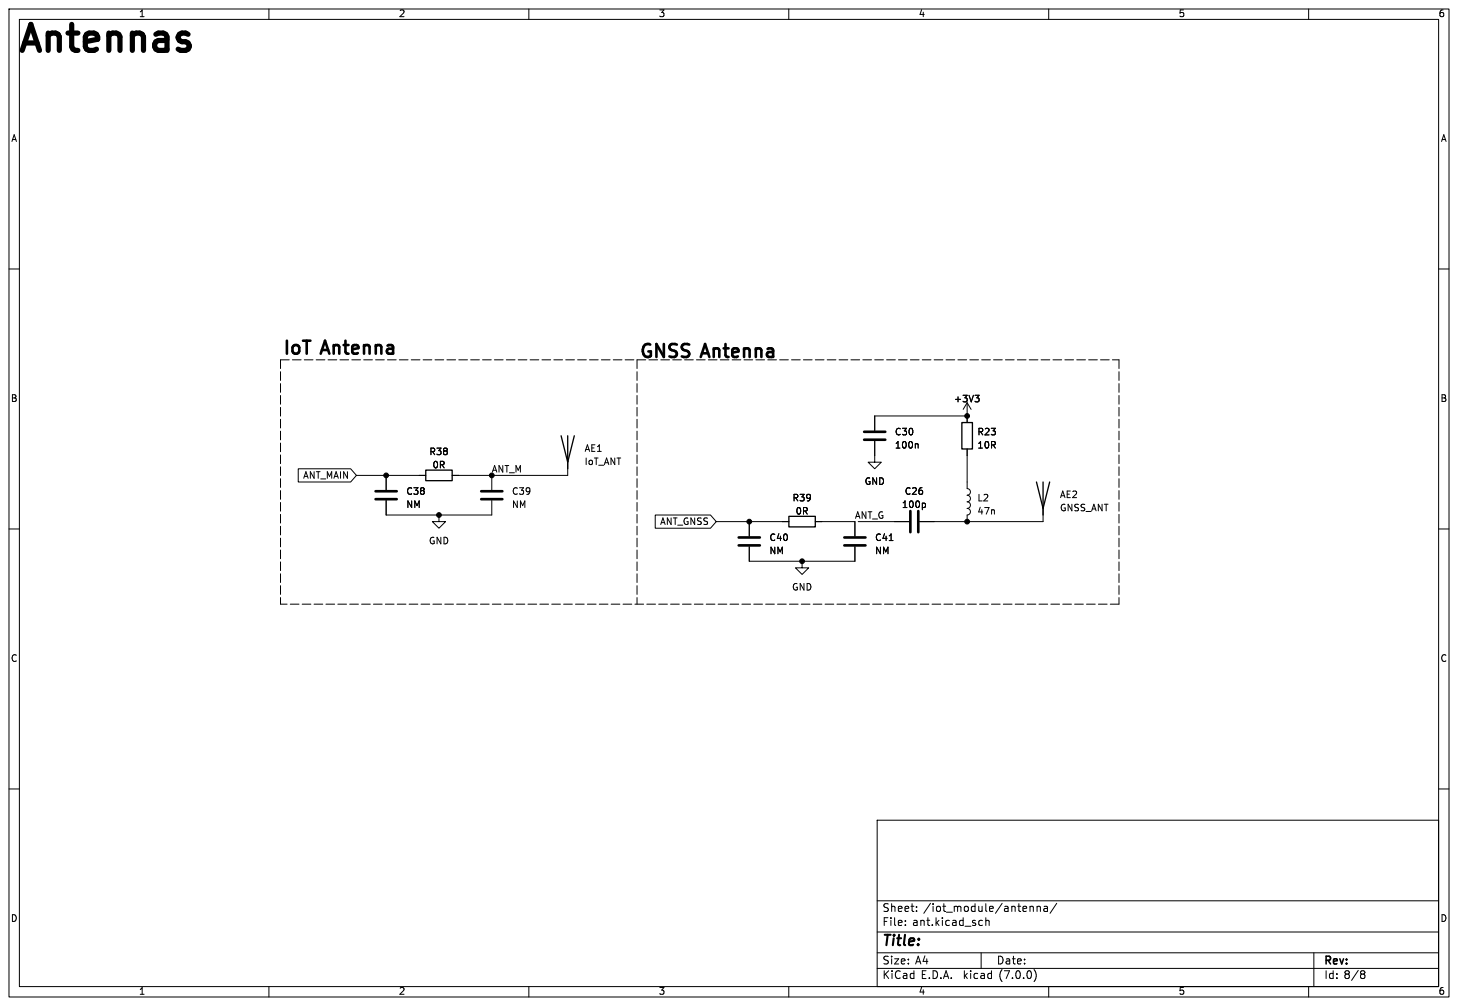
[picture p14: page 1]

Id: 8/8 Title: File: ant.kicad_sch Sheet: /iot_module/antenna/

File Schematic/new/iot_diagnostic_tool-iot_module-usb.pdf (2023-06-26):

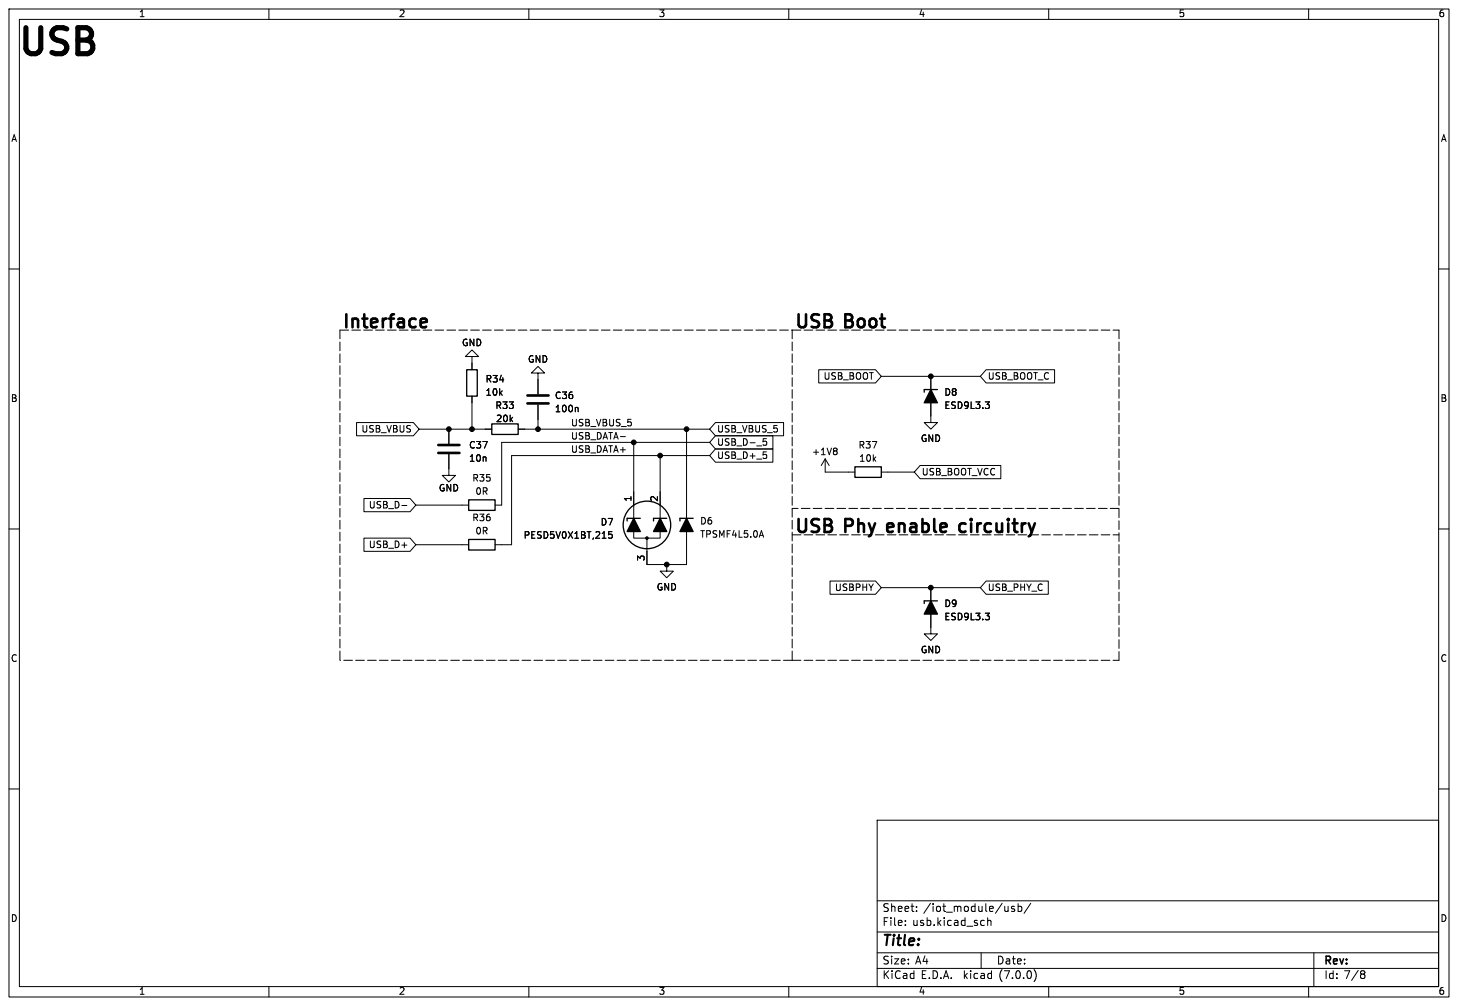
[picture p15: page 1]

Id: 7/8 Title: File: usb.kicad_sch Sheet: /iot_module/usb/

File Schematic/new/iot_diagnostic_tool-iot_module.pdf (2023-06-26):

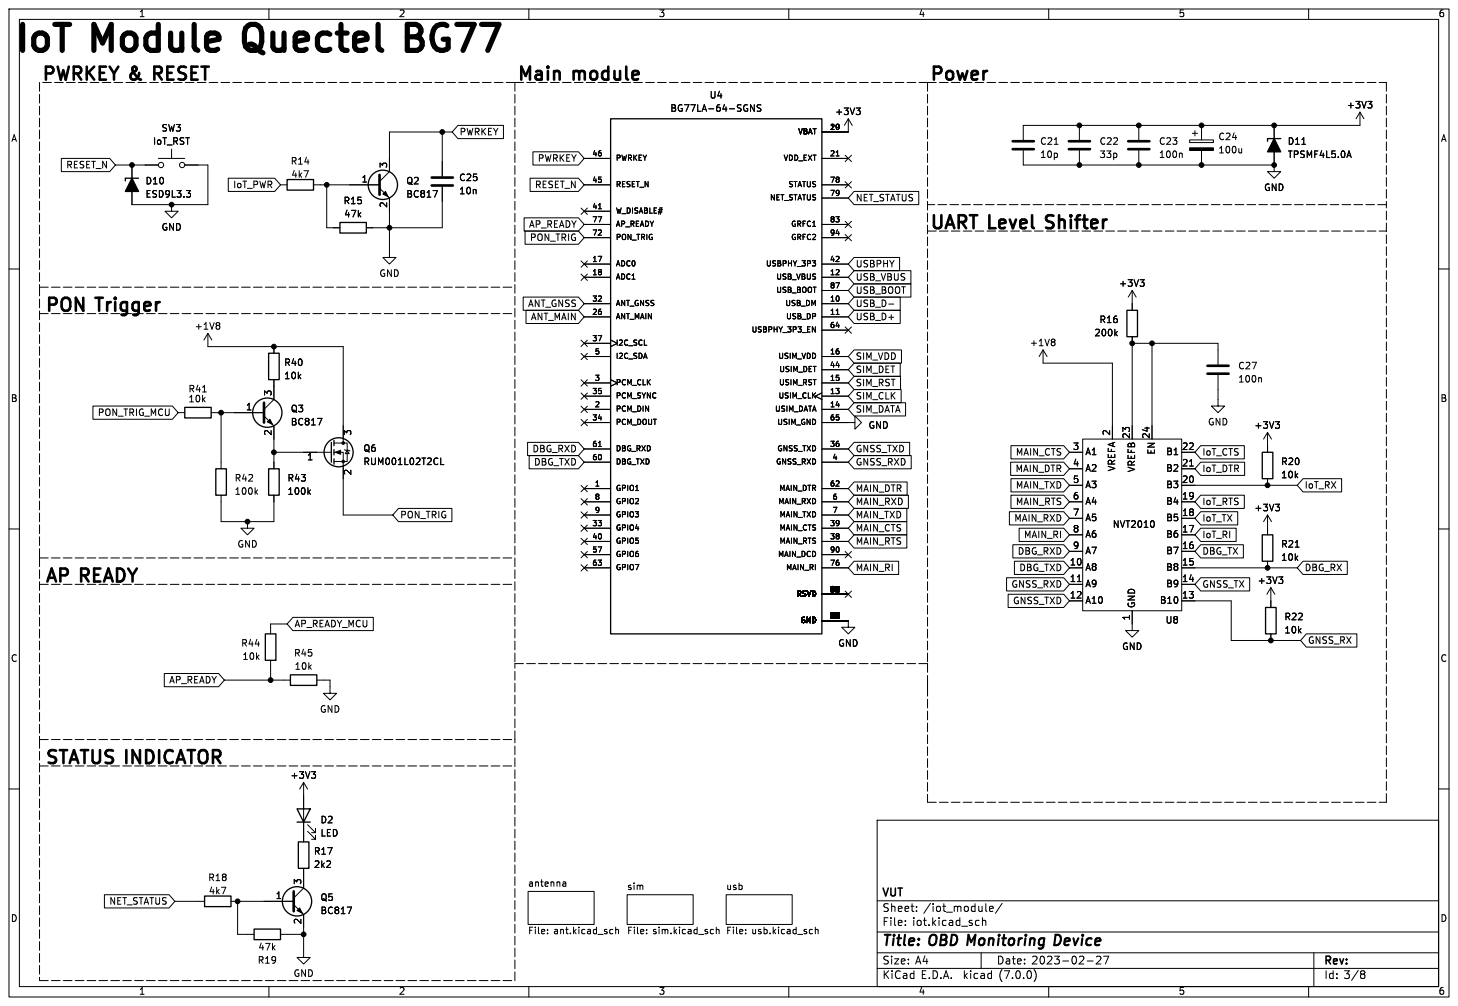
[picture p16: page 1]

File: iot.kicad_sch Sheet: /iot_module/ VUT

Id: 3/8 Title: OBD Monitoring Device

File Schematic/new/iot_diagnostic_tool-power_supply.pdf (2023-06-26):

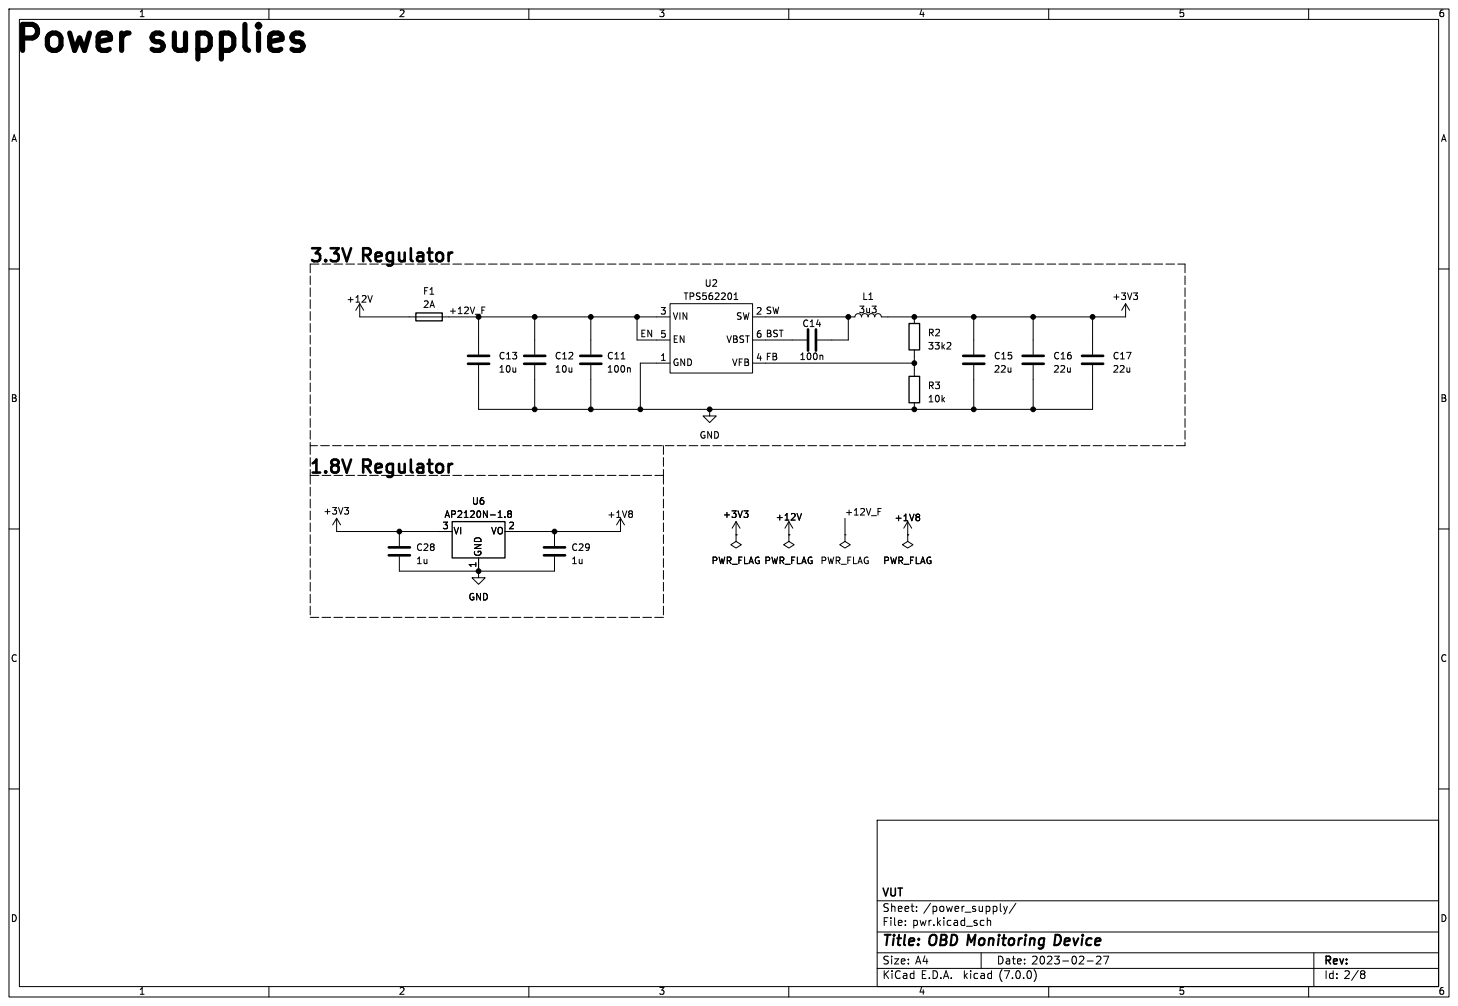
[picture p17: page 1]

File: pwr.kicad_sch Sheet: /power_supply/ VUT

Id: 2/8 Title: OBD Monitoring Device

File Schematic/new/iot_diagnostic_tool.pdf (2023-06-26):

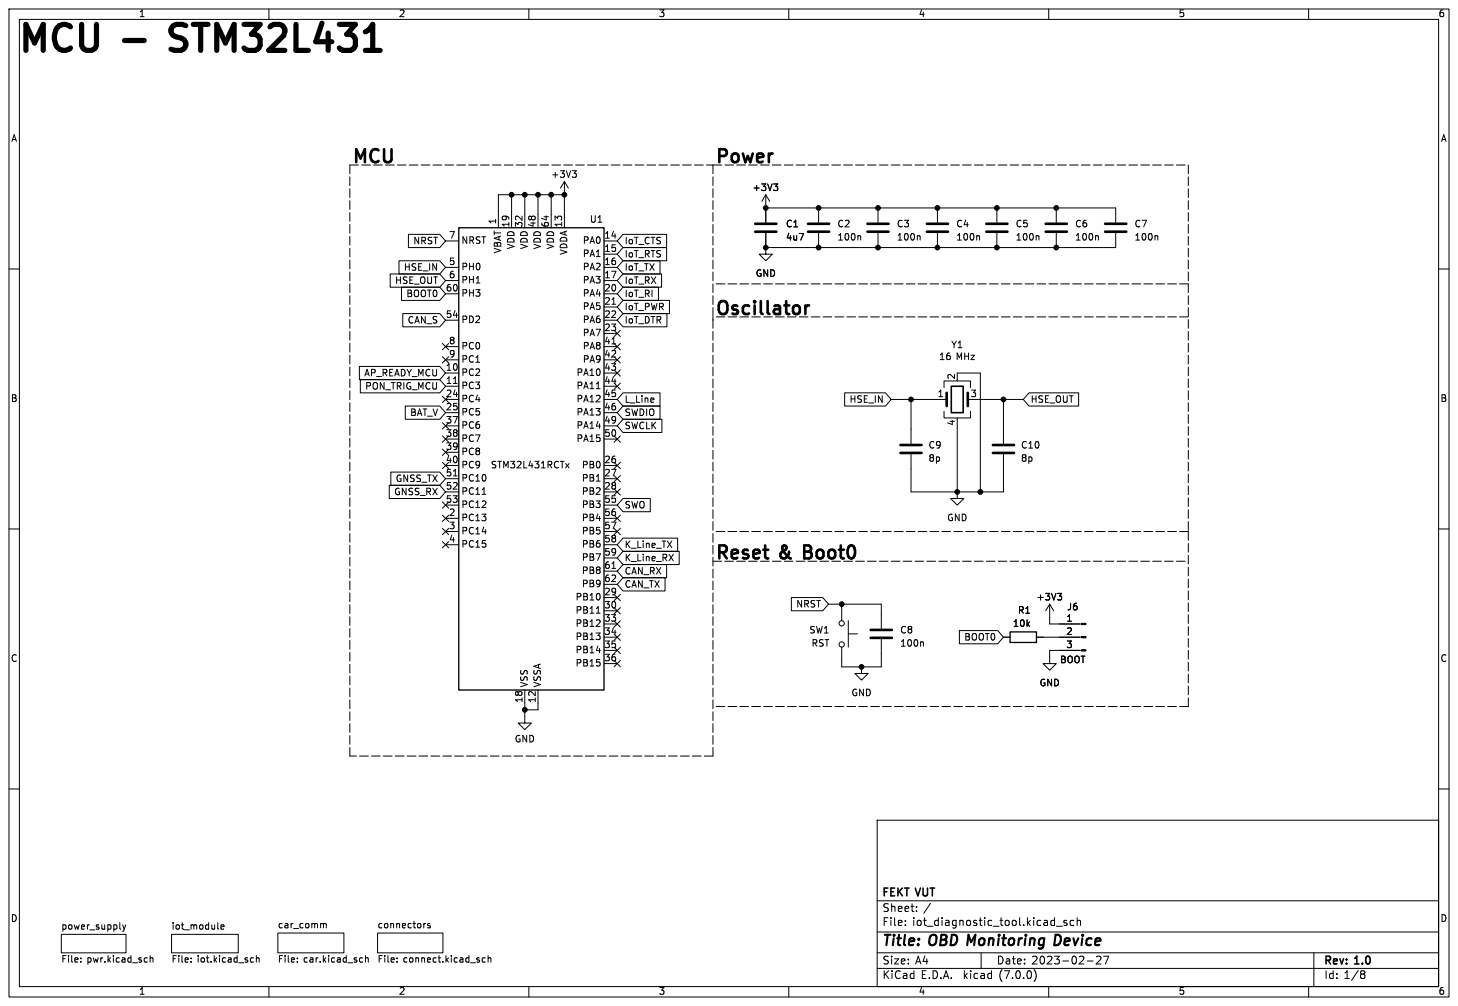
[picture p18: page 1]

1 PC2 10 PC3 11 VSSA 12 VDDA 13 PA0 14 PA1 15 PA2 16 PA3 17 VSS 18 VDD 19 PC13 2 PA4 20 PA5 21 PA6 22 PA7 23 PC4 24 PC5 25 PB0 26 PB1 27 PB2 28 PB10 29 PC14 3 PB11 30 VDD 32 PB12 33 PB13 34 PB14 35 PB15 36 PC6 37 PC7 38 PC8 39 PC15 4 PC9 40 PA8 41 PA9 42 PA10 43 PA11 44 PA12 45 PA13 46 VDD 48 PA14 49 PH0 5 PA15 50 PC10 51 PC11 52 PC12 53 PD2 54 PB3 55 PB4 56 PB5 57 PB6 58 PB7 59 PH1 6 PH3 60 PB8 61 PB9 62 VDD 64 NRST 7 PC0 8 PC1 9 U1 STM32L431RCTx GND

File: iot_diagnostic_tool.kicad_sch Sheet: / FEKT VUT

Id: 1/8 Title: OBD Monitoring Device

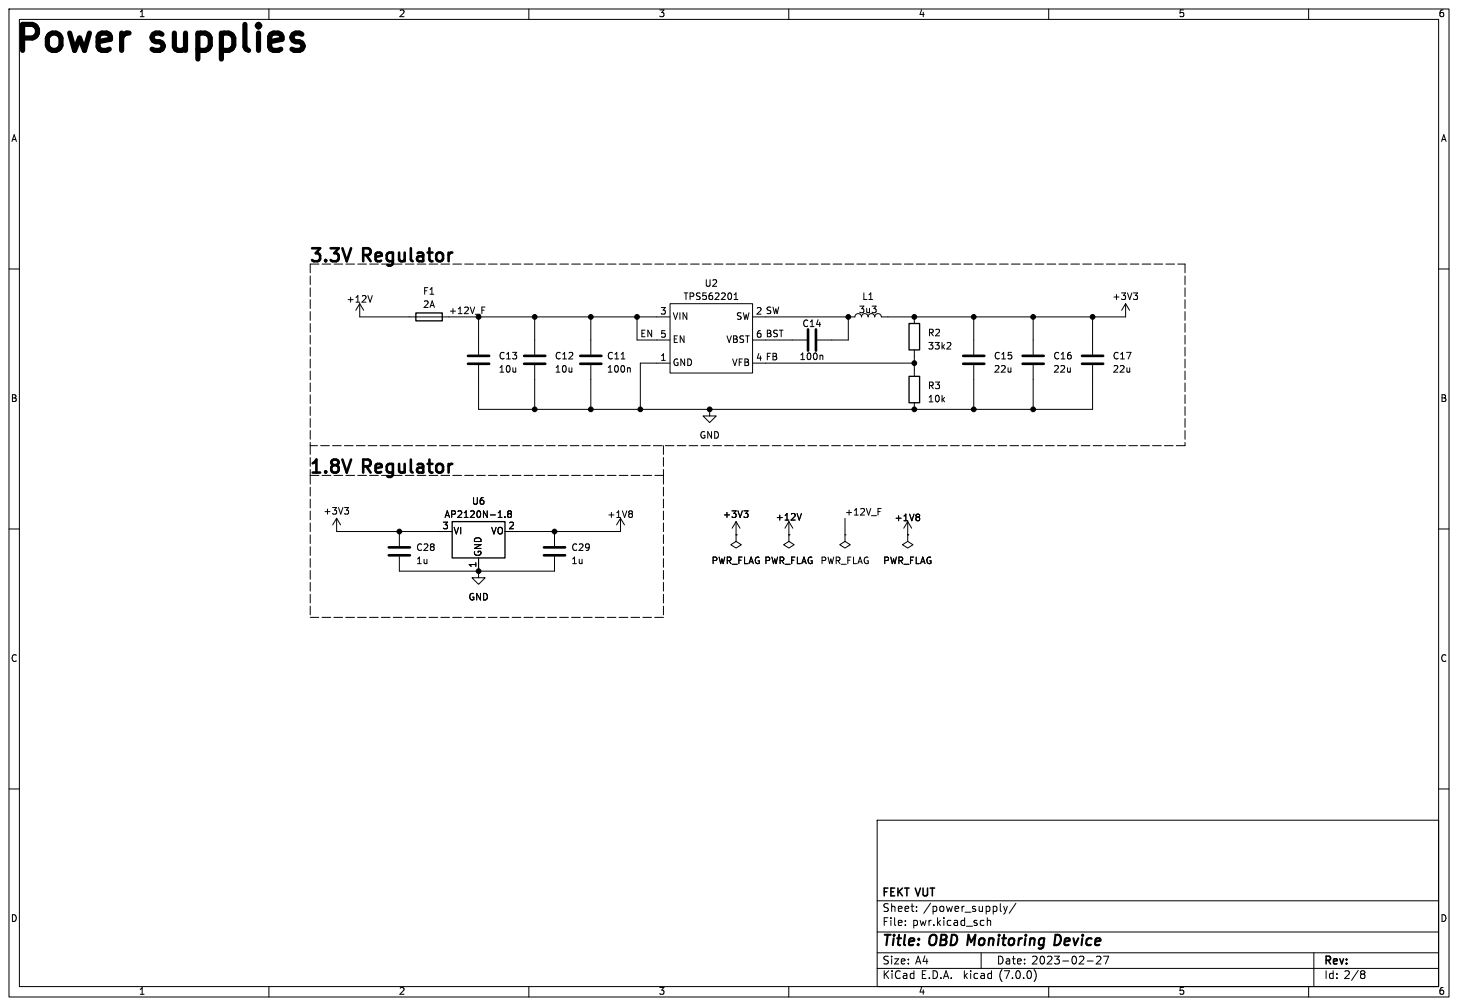
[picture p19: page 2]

File: pwr.kicad_sch Sheet: /power_supply/ FEKT VUT

Id: 2/8 Title: OBD Monitoring Device


File: iot.kicad_sch Sheet: /iot_module/ FEKT VUT

Id: 3/8 Title: OBD Monitoring Device


File: connect.kicad_sch Sheet: /connectors/ FEKT VUT

Id: 4/8 Title: OBD Monitoring Device


File: car.kicad_sch Sheet: /car_comm/ FEKT VUT GND

Id: 5/8 Title: OBD Monitoring Device


Id: 6/8 Title: OBD Monitoring Device


File: usb.kicad_sch Sheet: /iot_module/usb/ FEKT VUT

Id: 7/8 Title: OBD Monitoring Device


File: ant.kicad_sch Sheet: /iot_module/antenna/ FEKT VUT C38 NM
47n GND

Id: 8/8 Title: OBD Monitoring Device












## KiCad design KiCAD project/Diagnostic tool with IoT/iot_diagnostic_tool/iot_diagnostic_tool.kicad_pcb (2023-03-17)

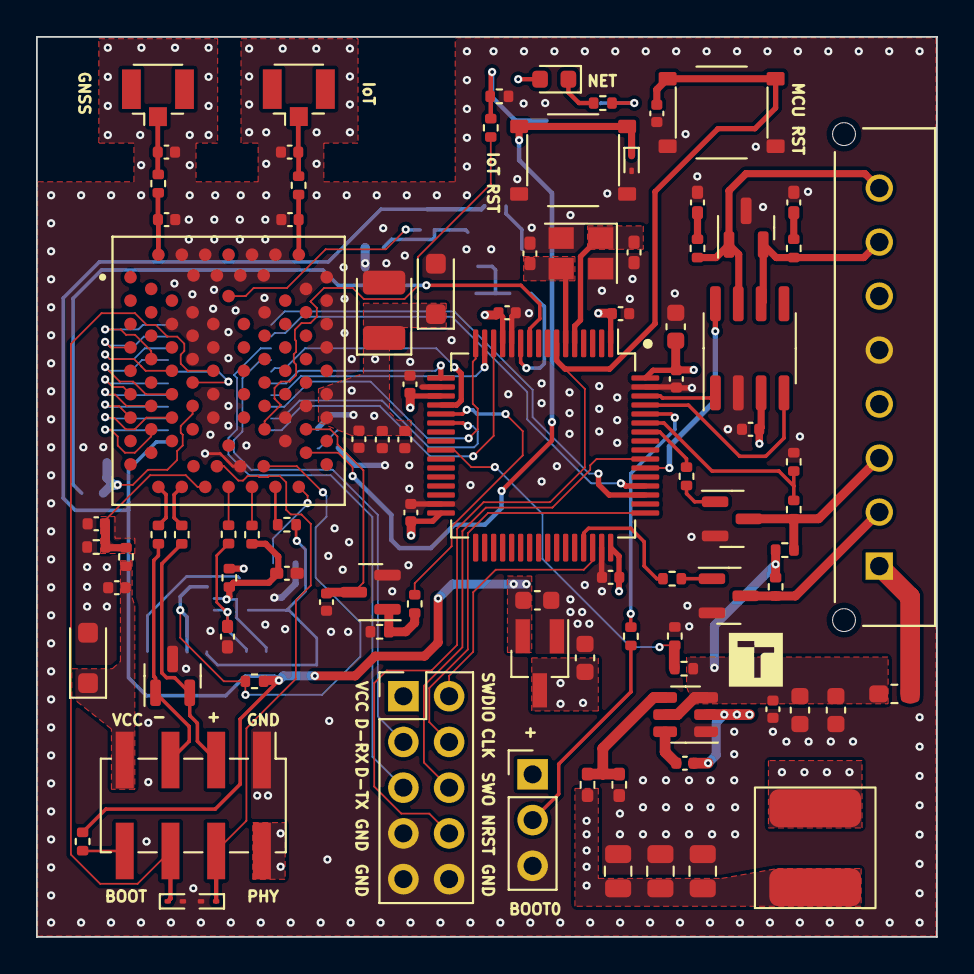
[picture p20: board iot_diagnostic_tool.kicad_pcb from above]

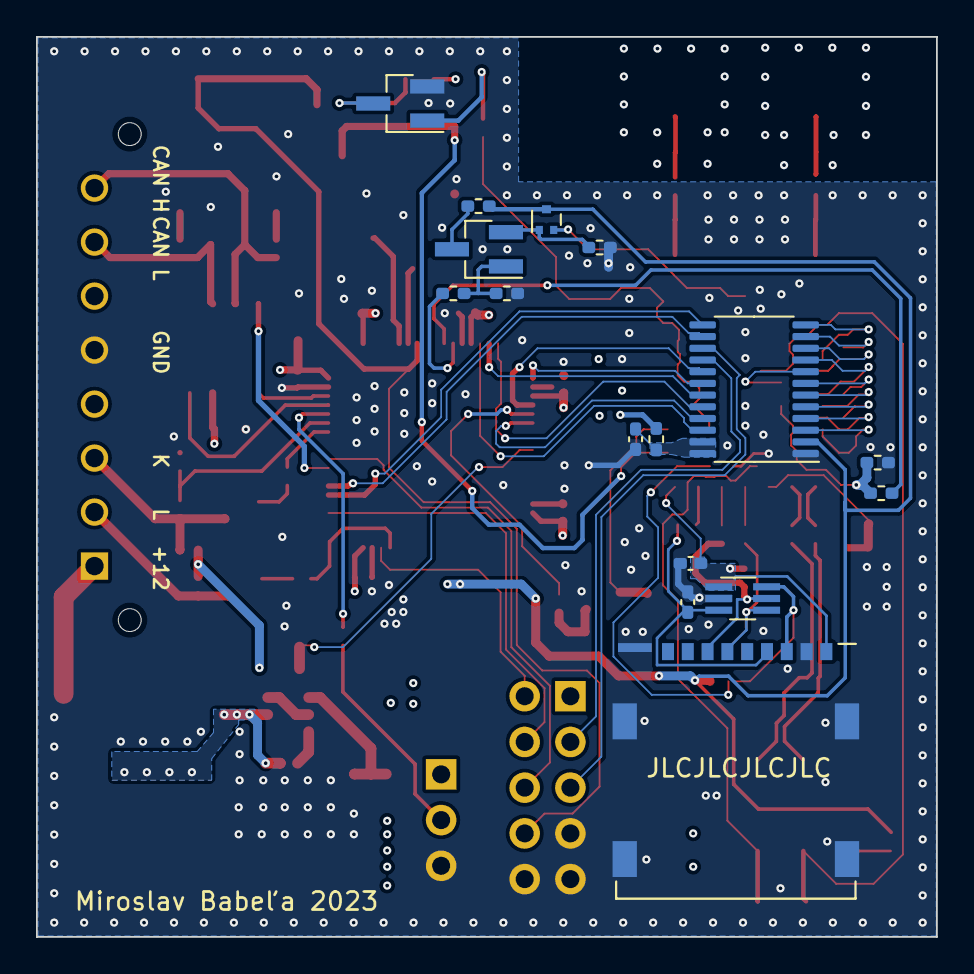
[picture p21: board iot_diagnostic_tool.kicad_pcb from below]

Board: 4 copper layers, 50.0 x 50.0 mm, 108 parts (16 on the bottom side), 88 nets.

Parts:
AE1: IoT_ANT; U.FL_Hirose_U.FL-R-SMT-1_Vertical
AE2: GNSS_ANT; U.FL_Hirose_U.FL-R-SMT-1_Vertical
C1: 4u7; C_0603_1608Metric
C2, C3, C4, C5, C6, C7, C8, C11, C14, C18, C23, C36: 100n; C_0402_1005Metric
C9, C10: 8p; C_0402_1005Metric_Pad0.74x0.62mm_HandSolder
C12, C13: 10u; C_0603_1608Metric
C15, C16, C17: 22u; C_0805_2012Metric
C19, C20: 560p; C_0402_1005Metric_Pad0.74x0.62mm_HandSolder
C21: 10p; C_0402_1005Metric
C22: 33p; C_0402_1005Metric
C24: 100u; CP_EIA-3528-21_Kemet-B
C25, C37: 10n; C_0402_1005Metric
C27, C32: 100n; C_0402_1005Metric_Pad0.74x0.62mm_HandSolder
C28, C29: 1u; C_0603_1608Metric
C33, C34, C35: 33p; C_0402_1005Metric_Pad0.74x0.62mm_HandSolder
C38, C39, C40, C41: NM; C_0402_1005Metric
D1: PESD2CAN; SOT-23
D2: LED; D_0603_1608Metric
D5: PESD5V0L5UY; SOT-363_SC-70-6_Handsoldering
D6, D11: TPSMF4L5.0A; D_SOD-123F
D7: PESD5V0X1BT,215; SOT-23
D8, D9, D10: ESD9L3.3; D_SOD-923
F1: 2A; Fuse_0603_1608Metric_Pad1.05x0.95mm_HandSolder
J2: USB; PinHeader_2x04_P2.54mm_Vertical_SMD
J3: 693023010811
J5: Debug; PinHeader_2x05_P2.54mm_Vertical
J6: BOOT; PinHeader_1x03_P2.54mm_Vertical
J7: OBD; MOLEX_436500827
L1: 3u3; VLS6045AF
Q1, Q2, Q4: BC817; SOT-23
Q3, Q5: BC817; SOT-23_Handsoldering
Q6: RUM001L02T2CL; SOT-723
R1, R34, R37: 10k; R_0402_1005Metric
R2: 33k2; R_0402_1005Metric_Pad0.72x0.64mm_HandSolder
R3, R40, R41, R44, R45: 10k; R_0402_1005Metric_Pad0.72x0.64mm_HandSolder
R4, R5: 100R; R_0402_1005Metric
R6, R8, R17: 2k2; R_0402_1005Metric
R7, R9: 510R; R_0402_1005Metric
R10, R12: 100k; R_0402_1005Metric
R11, R13: 27k; R_0402_1005Metric
R14, R18: 4k7; R_0402_1005Metric
R15, R19: 47k; R_0402_1005Metric
R16: 200k; R_0402_1005Metric_Pad0.72x0.64mm_HandSolder
R28, R29, R30, R35, R36, R38, R39: 0R; R_0402_1005Metric
R31: 51k; R_0402_1005Metric
R32: 15k; R_0402_1005Metric
R33: 20k; R_0402_1005Metric
R42, R43: 100k; R_0402_1005Metric_Pad0.72x0.64mm_HandSolder
SW1: RST; XKB_TS_1187A
SW3: IoT_RST; XKB_TS_1187A
U1: STM32L431RCTx; LQFP-64_10x10mm_P0.5mm
U2: TPS562201; SOT-23-6
U3: SN65HVD231; SOIC-8_3.9x4.9mm_P1.27mm
U4: BG77LA-64-SGNS; MODULE_BG77LA-64-SGNS
U6: AP2120N-1.8; SOT-23_Handsoldering
U8: NVT2010; TSSOP-24_4.4x7.8mm_P0.65mm
Y1: 16 MHz; Crystal_SMD_3225-4Pin_3.2x2.5mm

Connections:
+1V8: C29.1, Q6.3 (D), R31.1, R37.1, R40.1, U6.2 (VO), U8.2 (VREFA)
+3V3: C1.1, C2.1, C3.1, C4.1, C5.1, C6.1, C7.1, C15.1, C16.1, C17.1, C18.1, C21.1, C22.1, C23.1, C24.1, C28.1, D2.2 (A), D11.1 (K), J2.2, J5.1, J6.1, L1.2, R2.1, R16.1, U1.1 (VBAT), U1.13 (VDDA), U1.19 (VDD), U1.32 (VDD), U1.48 (VDD), U1.64 (VDD), U3.3 (VCC), U4.19 (VBAT), U4.20 (VBAT), U6.3 (VI)
+12V: F1.1, J7.1
/iot_module/antenna/ANT_G: AE2.1 (A), C41.1, R39.2
/iot_module/antenna/ANT_M: AE1.1 (A), C39.1, R38.2
/iot_module/sim/SIM_CL: C34.1, D5.4 (L3), J3.C3 (CLK), R29.2
/iot_module/sim/SIM_DAT: C35.1, D5.5 (L4), J3.C7 (I/O), R30.2, R32.2
/iot_module/sim/SIM_RES: C33.1, D5.3 (L2), J3.C2 (RST), R28.2
/power_supply/+12V_F: C11.1, C12.1, C13.1, F1.2, R7.1, R9.1, R12.1, U2.3 (VIN), U2.5 (EN)
/power_supply/BST: C14.2, U2.6 (VBST)
/power_supply/FB: R2.2, R3.1, U2.4 (VFB)
/power_supply/SW: C14.1, L1.1, U2.2 (SW)
ANT_GNSS: C40.1, R39.1, U4.32 (ANT_GNSS)
ANT_MAIN: C38.1, R38.1, U4.26 (ANT_MAIN)
AP_READY: R44.2, R45.1, U4.77 (AP_READY)
AP_READY_MCU: R44.1, U1.10 (PC2)
BAT_V: R12.2, R13.1, U1.25 (PC5)
BOOT0: R1.1, U1.60 (PH3)
CAN_H: D1.1 (A1), J7.8, R5.1, U3.7 (CANH)
CAN_L: D1.2 (A2), J7.7, R4.1, U3.6 (CANL)
CAN_RX: U1.61 (PB8), U3.4 (R)
CAN_S: U1.54 (PD2), U3.8 (Rs)
CAN_TX: U1.62 (PB9), U3.1 (D)
DBG_RX: J5.3, U8.16 (B7)
DBG_RXD: U4.61 (DBG_RXD), U8.9 (A7)
DBG_TX: J5.5, U8.15 (B8)
DBG_TXD: U4.60 (DBG_TXD), U8.10 (A8)
GND: C1.2, C2.2, C3.2, C4.2, C5.2, C6.2, C7.2, C8.2, C9.2, C10.2, C11.2, C12.2, C13.2, C15.2, C16.2, C17.2, C18.2, C19.2, C20.2, C21.2, C22.2, C23.2, C24.2, C25.2, C27.2, C28.2, C29.2, C32.2, C33.2, C34.2, C35.2, C36.1, C37.2, C38.2, C39.2, C40.2, C41.2, D1.3 (Com), D5.2 (VN), D6.2 (A), D7.3 (A), D8.2 (A), D9.2 (A), D10.2 (A), D11.2 (A), J2.1, J3.C5 (GND), J3.Z1 (GND1), J3.Z2 (GND1), J3.Z3 (GND1), J3.Z4 (GND1), J3.Z5 (GND1), J5.7, J5.9, J5.10, J6.3, J7.5, Q1.2 (E), Q2.2 (E), Q4.2 (E), Q5.2 (E), R3.2, R11.2, R13.2, R15.1, R19.1, R34.1, R42.2, R43.2, R45.2, SW1.1, SW3.2, U1.12 (VSSA), U1.18 (VSS), U1.31 (VSS), U1.47 (VSS), U1.63 (VSS), U2.1 (GND), U3.2 (GND), U4.22 (GND), U4.23 (GND), U4.24 (GND), U4.25 (GND), U4.27 (GND), U4.28 (GND), U4.30 (GND), U4.31 (GND), U4.43 (GND), U4.47 (GND), U4.52 (GND), U4.53 (GND), U4.54 (GND), U4.55 (GND), U4.56 (GND), U4.58 (GND), U4.65 (USIM_GND), U4.66 (GND), U4.73 (GND), U4.74 (GND), U4.75 (GND), U4.84 (GND), U4.85 (GND), U4.86 (GND), U4.88 (GND), U4.89 (GND), U6.1 (GND), U8.1 (GND), Y1.2, Y1.4
GNSS_RX: U1.52 (PC11), U8.14 (B9)
GNSS_RXD: U4.4 (GNSS_RXD), U8.11 (A9)
GNSS_TX: U1.51 (PC10), U8.13 (B10)
GNSS_TXD: U4.36 (GNSS_TXD), U8.12 (A10)
HSE_IN: C9.1, U1.5 (PH0), Y1.1
HSE_OUT: C10.1, U1.6 (PH1), Y1.3
ISO_K: J7.3, Q1.3 (C), R7.2, R10.1
ISO_L: J7.2, Q4.3 (C), R9.2
IoT_CTS: U1.14 (PA0), U8.22 (B1)
IoT_DTR: U1.22 (PA6), U8.21 (B2)
IoT_PWR: R14.1, U1.21 (PA5)
IoT_RI: U1.20 (PA4), U8.17 (B6)
IoT_RTS: U1.15 (PA1), U8.19 (B4)
IoT_RX: U1.17 (PA3), U8.18 (B5)
IoT_TX: U1.16 (PA2), U8.20 (B3)
K_Line_RX: R10.2, R11.1, U1.59 (PB7)
K_Line_TX: R6.2, U1.58 (PB6)
L_Line: R8.2, U1.45 (PA12)
MAIN_CTS: U4.39 (MAIN_CTS), U8.3 (A1)
MAIN_DTR: U4.62 (MAIN_DTR), U8.4 (A2)
MAIN_RI: U4.76 (MAIN_RI), U8.8 (A6)
MAIN_RTS: U4.38 (MAIN_RTS), U8.6 (A4)
MAIN_RXD: U4.6 (MAIN_RXD), U8.7 (A5)
MAIN_TXD: U4.7 (MAIN_TXD), U8.5 (A3)
NET_STATUS: R18.1, U4.79 (NET_STATUS)
NRST: C8.1, J5.8, SW1.2, U1.7 (NRST)
unnamed: C19.1, R4.2
unnamed: C20.1, R5.2
unnamed: D2.1 (K), R17.1
unnamed: J6.2, R1.2
unnamed: Q1.1 (B), R6.1
unnamed: Q2.1 (B), R14.2, R15.2
unnamed: Q3.1 (B), R41.2, R42.1
unnamed: Q3.3 (C), R40.2
unnamed: Q3.2 (E), Q6.1 (G), R43.1
unnamed: Q4.1 (B), R8.1
unnamed: Q5.1 (B), R18.2, R19.2
unnamed: Q5.3 (C), R17.2
unnamed: C27.1, R16.2, U8.23 (VREFB), U8.24 (EN)
PON_TRIG: Q6.2 (S), U4.72 (PON_TRIG)
PON_TRIG_MCU: R41.1, U1.11 (PC3)
PWRKEY: C25.1, Q2.3 (C), U4.46 (PWRKEY)
RESET_N: D10.1 (K), SW3.1, U4.45 (RESET_N)
SIM_CLK: R29.1, U4.13 (USIM_CLK)
SIM_DATA: R30.1, U4.14 (USIM_DATA)
SIM_DET: D5.6 (L5), J3.SW (DETECTION), R31.2, U4.44 (USIM_DET)
SIM_RST: R28.1, U4.15 (USIM_RST)
SIM_VDD: C32.1, D5.1 (L1), J3.C1 (VCC), R32.1, U4.16 (USIM_VDD)
SWCLK: J5.4, U1.49 (PA14)
SWDIO: J5.2, U1.46 (PA13)
SWO: J5.6, U1.55 (PB3)
USBPHY: D9.1 (K), J2.4, U4.42 (USBPHY_3P3)
USB_BOOT: D8.1 (K), J2.6, U4.87 (USB_BOOT)
USB_BOOT_VCC: J2.8, R37.2
USB_D+: R36.1, U4.11 (USB_DP)
USB_D+_5: D7.2 (K2), J2.3, R36.2
USB_D-: R35.1, U4.10 (USB_DM)
USB_D-_5: D7.1 (K1), J2.5, R35.2
USB_VBUS: C37.1, R33.1, R34.2, U4.12 (USB_VBUS)
USB_VBUS_5: C36.2, D6.1 (K), J2.7, R33.2

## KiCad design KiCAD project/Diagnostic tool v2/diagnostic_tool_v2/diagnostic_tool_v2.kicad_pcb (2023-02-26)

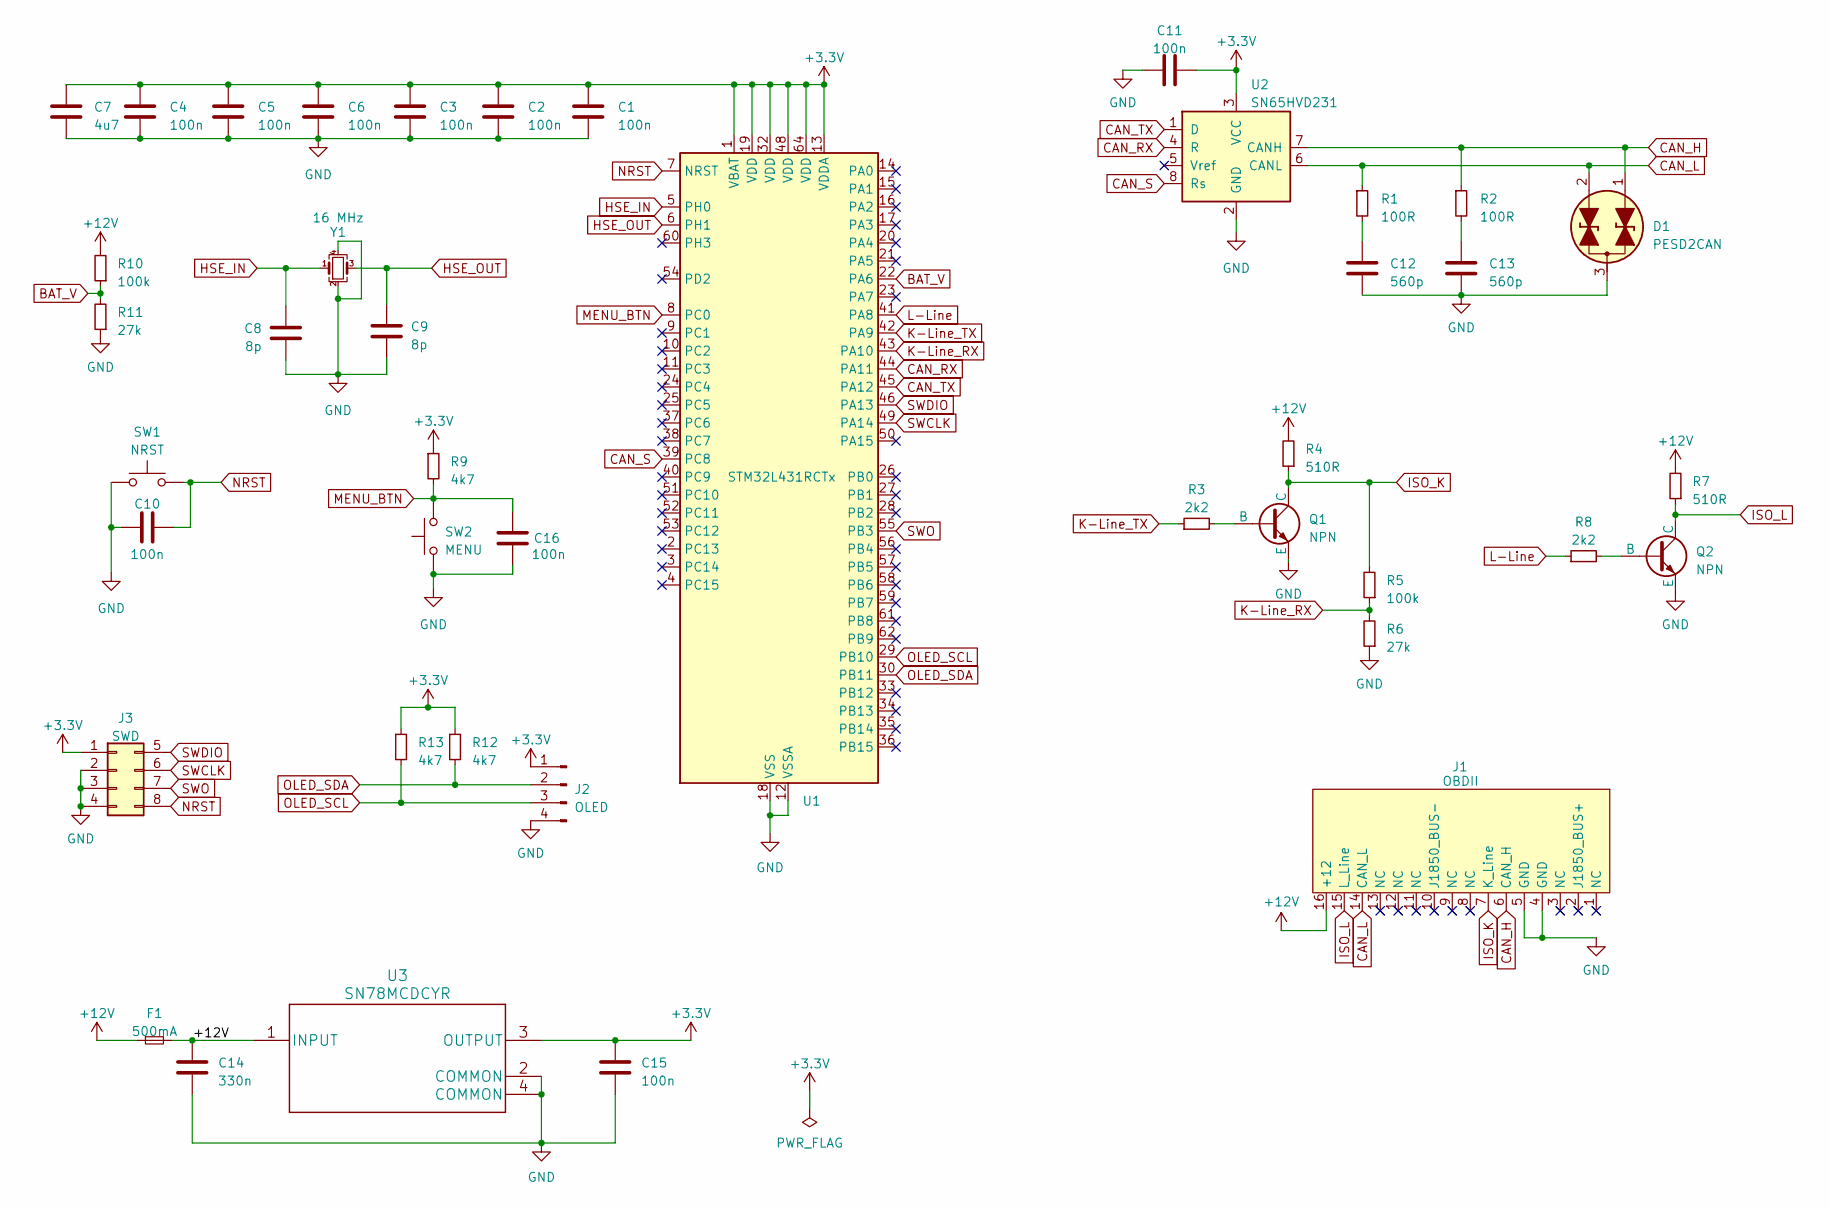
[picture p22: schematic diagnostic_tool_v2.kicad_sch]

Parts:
C1, C2, C3, C4, C5, C6, C10, C11, C15, C16: 100n; C_0402_1005Metric
C7: 4u7; C_0603_1608Metric
C8, C9: 8p; C_0402_1005Metric
C12, C13: 560p; C_0402_1005Metric
C14: 330n; C_0603_1608Metric
D1: PESD2CAN; SOT-23
F1: 500mA; Fuse_1206_3216Metric_Pad1.42x1.75mm_HandSolder
J1: OBDII; OBD
J2: OLED; PinHeader_1x04_P1.27mm_Vertical
J3: SWD; PinHeader_2x04_P1.27mm_Vertical
Q1, Q2: NPN; SOT-23
R1, R2: 100R; R_0402_1005Metric
R3, R8: 2k2; R_0402_1005Metric
R4, R7: 510R; R_0402_1005Metric
R5, R10: 100k; R_0402_1005Metric
R6, R11: 27k; R_0402_1005Metric
R9, R12, R13: 4k7; R_0402_1005Metric
SW1: NRST; XKB_TS_1187A
SW2: MENU; PinHeader_1x02_P1.27mm_Vertical
U1: STM32L431RCTx; LQFP-64_10x10mm_P0.5mm
U2: SN65HVD231; SOIC-8_3.9x4.9mm_P1.27mm
U3: SN78MCDCYR; SOT-223
Y1: 16 MHz; Crystal_SMD_TXC_7M-4Pin_3.2x2.5mm

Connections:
+3.3V: C1.1, C2.1, C3.1, C4.1, C5.1, C6.1, C7.1, C11.2, C15.1, J2.1, J3.1, R9.1, R12.1, R13.1, U1.1 (VBAT), U1.13 (VDDA), U1.19 (VDD), U1.32 (VDD), U1.48 (VDD), U1.64 (VDD), U2.3 (VCC), U3.3 (OUTPUT)
+12V: C14.1, F1.1, F1.2, J1.16 (+12), R4.2, R7.2, R10.2, U3.1 (INPUT)
BAT_V: R10.1, R11.2, U1.22 (PA6)
CAN_H: D1.1 (A1), J1.6 (CAN_H), R2.1, U2.7 (CANH)
CAN_L: D1.2 (A2), J1.14 (CAN_L), R1.1, U2.6 (CANL)
CAN_RX: U1.44 (PA11), U2.4 (R)
CAN_S: U1.39 (PC8), U2.8 (Rs)
CAN_TX: U1.45 (PA12), U2.1 (D)
GND: C1.2, C2.2, C3.2, C4.2, C5.2, C6.2, C7.2, C8.2, C9.2, C10.1, C11.1, C12.1, C13.1, C14.2, C15.2, C16.2, D1.3 (Com), J1.4 (GND), J1.5 (GND), J2.4, J3.2, J3.3, J3.4, Q1.3 (E), Q2.3 (E), R6.1, R11.1, SW1.1, SW2.1, U1.12 (VSSA), U1.18 (VSS), U1.31 (VSS), U1.47 (VSS), U1.63 (VSS), U2.2 (GND), U3.2 (COMMON), U3.4 (COMMON), Y1.2, Y1.4
HSE_IN: C8.1, U1.5 (PH0), Y1.1
HSE_OUT: C9.1, U1.6 (PH1), Y1.3
ISO_K: J1.7 (K_Line), Q1.1 (C), R4.1, R5.2
ISO_L: J1.15 (L_Line), Q2.1 (C), R7.1
K-Line_RX: R5.1, R6.2, U1.43 (PA10)
K-Line_TX: R3.1, U1.42 (PA9)
L-Line: R8.1, U1.41 (PA8)
MENU_BTN: C16.1, R9.2, SW2.2, U1.8 (PC0)
NRST: C10.2, J3.8, SW1.2, U1.7 (NRST)
unnamed: C12.2, R1.2
unnamed: C13.2, R2.2
unnamed: Q1.2 (B), R3.2
unnamed: Q2.2 (B), R8.2
OLED_SCL: J2.3, R13.2, U1.29 (PB10)
OLED_SDA: J2.2, R12.2, U1.30 (PB11)
SWCLK: J3.6, U1.49 (PA14)
SWDIO: J3.5, U1.46 (PA13)
SWO: J3.7, U1.55 (PB3)

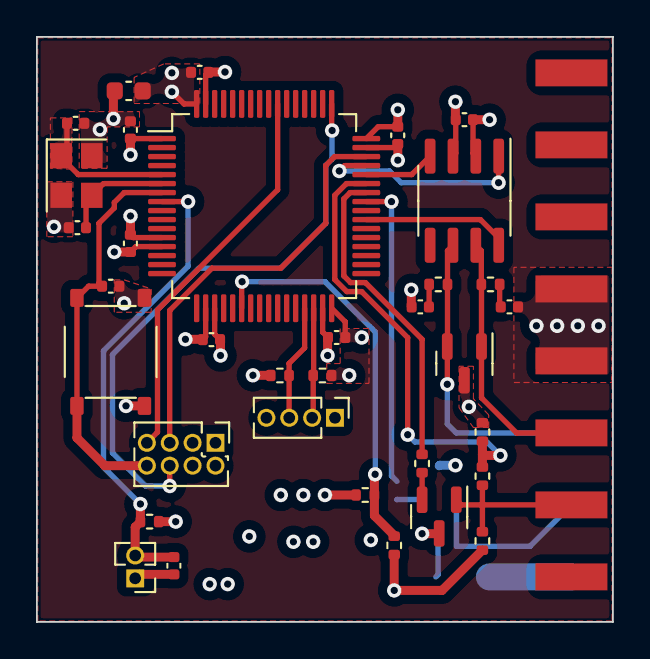
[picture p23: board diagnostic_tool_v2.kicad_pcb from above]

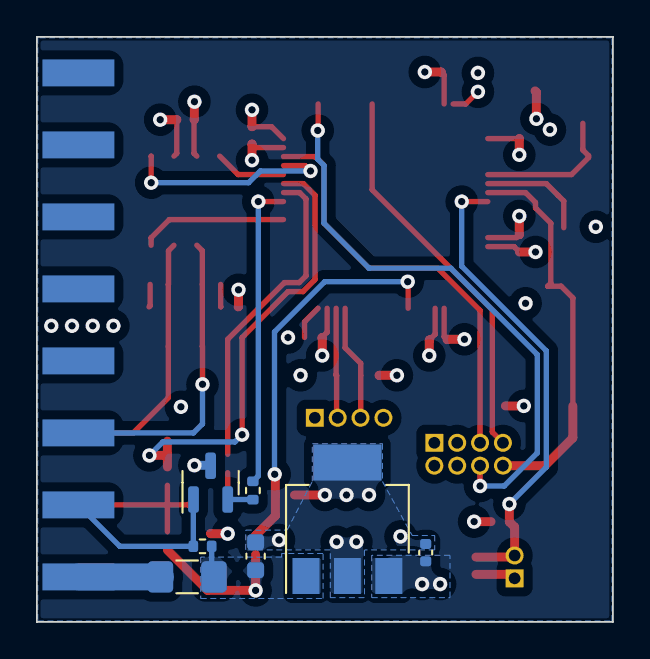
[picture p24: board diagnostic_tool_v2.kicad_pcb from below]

Board: 4 copper layers, 32.0 x 32.5 mm, 42 parts (7 on the bottom side), 27 nets.

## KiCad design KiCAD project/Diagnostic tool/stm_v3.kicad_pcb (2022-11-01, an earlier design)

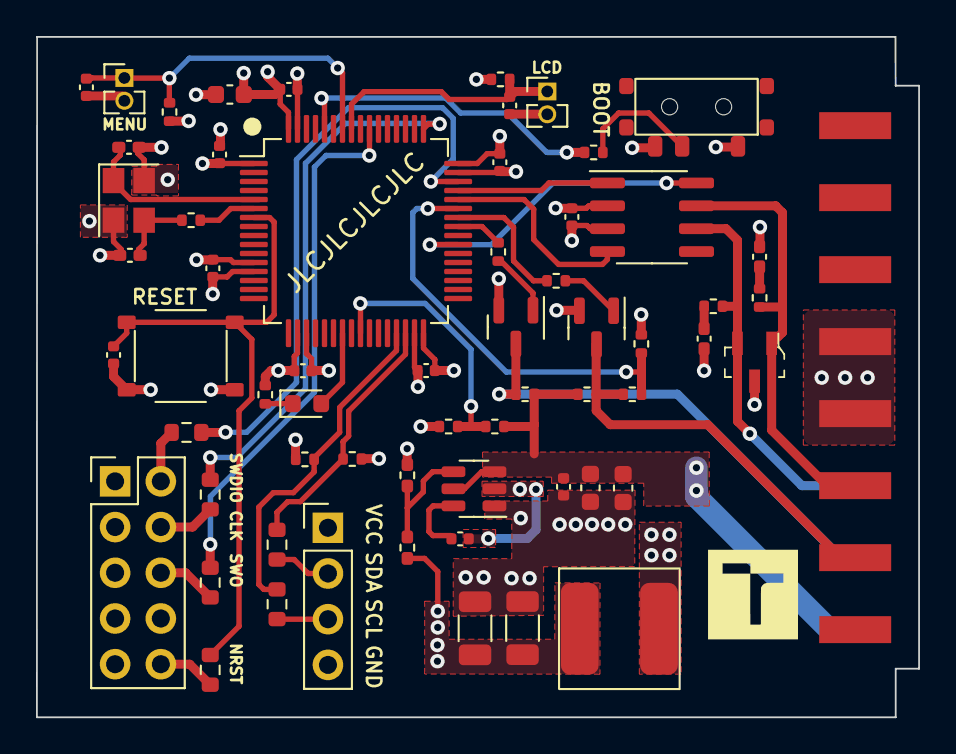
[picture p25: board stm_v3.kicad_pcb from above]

Board: 4 copper layers, 49.0 x 37.8 mm, 62 parts (0 on the bottom side), 42 nets.

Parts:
C1: 4u7; C_0603_1608Metric
C2, C3, C4, C5, C6, C7, C10, C11, C16, C17, C20, C21: 100n; C_0402_1005Metric
C8, C9: 8p; C_0402_1005Metric_Pad0.74x0.62mm_HandSolder
C12, C13: 560p; C_0402_1005Metric_Pad0.74x0.62mm_HandSolder
C14, C15: 10u; C_0603_1608Metric
C18, C19: 22u; C_1206_3216Metric
D1: PESD2CAN_215; SOT-23-3
D2: LED; LED_0603_1608Metric
J1: OLED; PinHeader_1x04_P2.54mm_Vertical
J2: SWD; PinHeader_2x05_P2.54mm_Vertical
J3: OBDII; OBD
L1: 3u3; VLS6045AF
Q1, Q2: s8050; SOT-23
R1, R2: 100R; R_0402_1005Metric
R3: 0R; R_0402_1005Metric
R4, R15: 10k; R_0402_1005Metric
R5, R6, R7, R8, R9, R10: 22R; R_0603_1608Metric
R11, R12, R24, R25: 4k7; R_0402_1005Metric
R13: 33k2; R_0402_1005Metric_Pad0.72x0.64mm_HandSolder
R14: 10k; R_0402_1005Metric_Pad0.72x0.64mm_HandSolder
R16, R17: 510R; R_0402_1005Metric
R18, R19: 2k2; R_0402_1005Metric
R20, R22: 100k; R_0402_1005Metric
R21, R23: 27k; R_0402_1005Metric
SW1: RST; XKB_TS_1187A
SW2: BOOT0; XKB_SS-3292S
SW3: LCD; PinHeader_1x02_P1.27mm_Vertical
SW4: MENU; PinHeader_1x02_P1.27mm_Vertical
U1: STM32L431RCTx; LQFP-64_10x10mm_P0.5mm
U2: SN65HVD231; SOIC-8_3.9x4.9mm_P1.27mm
U3: TPS562201; SOT-23-6
Y1: 16 MHz; Crystal_SMD_3225-4Pin_3.2x2.5mm

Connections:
+3.3V: C1.1, C2.1, C3.1, C4.1, C5.1, C6.1, C7.1, C11.1, C18.1, C19.1, J1.1, J2.1, L1.2, R11.1, R12.1, R13.1, R24.1, R25.1, SW2.3 (C), U1.1 (VBAT), U1.13 (VDDA), U1.19 (VDD), U1.32 (VDD), U1.48 (VDD), U1.64 (VDD), U2.3 (VCC)
+12V: C14.1, C15.1, C16.1, J3.16 (+12), R16.1, R17.1, R22.1, U3.3 (VIN), U3.5 (EN)
/B_0: R4.2, SW2.2 (B)
/Connectors/N_RST: J2.10, R10.1
/Connectors/SCL: J1.3, R6.2
/Connectors/SDA: J1.2, R5.2
/Connectors/SW_CLK: J2.4, R8.1
/Connectors/SW_DIO: J2.2, R7.1
/Connectors/SW_O: J2.6, R9.1
/HSE_O: C9.1, R3.1, Y1.3
/Power Supply/BST: C17.1, U3.6 (VBST)
/Power Supply/FB: R13.2, R14.1, U3.4 (VFB)
/Power Supply/SW: C17.2, L1.1, U3.2 (SW)
BAT_V: R22.2, R23.1, U1.25 (PC5)
BOOT0: R4.1, U1.60 (PH3)
CAN_H: D1.1 (C1), J3.6 (CAN_H), R2.1, U2.7 (CANH)
CAN_L: D1.2 (C2), J3.14 (CAN_L), R1.1, U2.6 (CANL)
CAN_RX: U1.44 (PA11), U2.4 (R)
CAN_S: U1.39 (PC8), U2.8 (Rs)
CAN_TX: U1.45 (PA12), U2.1 (D)
GND: C1.2, C2.2, C3.2, C4.2, C5.2, C6.2, C7.2, C8.2, C9.2, C10.2, C11.2, C12.2, C13.2, C14.2, C15.2, C16.2, C18.2, C19.2, C20.1, C21.1, D1.3 (C3), J1.4, J2.3, J2.5, J2.9, J3.4 (GND), J3.5 (GND), Q1.2 (E), Q2.2 (E), R14.2, R15.1, R21.1, R23.2, SW1.1, SW2.1 (A), SW3.2, SW4.2, U1.12 (VSSA), U1.18 (VSS), U1.31 (VSS), U1.47 (VSS), U1.63 (VSS), U2.2 (GND), U3.1 (GND), Y1.2, Y1.4
HSE_IN: C8.1, U1.5 (PH0), Y1.1
HSE_OUT: R3.2, U1.6 (PH1)
ISO_K: J3.7 (K_Line), Q2.3 (C), R17.2, R20.1
ISO_L: J3.15 (L_Line), Q1.3 (C), R16.2
KLine_RX: R20.2, R21.2, U1.43 (PA10)
KLine_TX: R19.1, U1.42 (PA9)
LCD_BTN: C20.2, R24.2, SW3.1, U1.57 (PB5)
LED: D2.2 (A), U1.23 (PA7)
LLine: R18.1, U1.41 (PA8)
MENU_BTN: C21.2, R25.2, SW4.1, U1.58 (PB6)
NRST: C10.1, R10.2, SW1.2, U1.7 (NRST)
unnamed: C12.1, R1.2
unnamed: C13.1, R2.2
unnamed: D2.1 (K), R15.2
unnamed: Q1.1 (B), R18.2
unnamed: Q2.1 (B), R19.2
OLED_SCL: R6.1, R11.2, U1.29 (PB10)
OLED_SDA: R5.1, R12.2, U1.30 (PB11)
SWCLK: R8.2, U1.49 (PA14)
SWDIO: R7.2, U1.46 (PA13)
SWO: R9.2, U1.55 (PB3)

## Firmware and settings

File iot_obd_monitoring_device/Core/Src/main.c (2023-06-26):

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
/* Includes ------------------------------------------------------------------*/
#include "main.h"
#include "adc.h"
#include "dma.h"
#include "tim.h"
#include "usart.h"
#include "gpio.h"


/* USER CODE BEGIN PV */

uint8_t uartBuf[10] = {0};

uint16_t adc_buffer[64] = {0};

OBD obd_comm;

BG77 module;

location pos;

/* USER CODE END PV */

void SystemClock_Config(void);
/* USER CODE BEGIN PFP */
static void acquire_vehicle_data(float buffer[][2], float buffer_old[][2]);
static uint8_t mqtt_start(BG77 module);
static uint8_t mqtt_stop(BG77 module);
static void create_json(char buff[1000], float array[][2], float array_cpy[][2], int num_of_values);
static void acquire_position(char buff[1000]);
static float measure_avg_voltage(uint16_t *data);
/* USER CODE END PFP */

/* USER CODE BEGIN 0 */
static void acquire_vehicle_data(float buffer[][2], float buffer_old[][2])
{
	uint8_t pids [3] = {0x5, 0xc, 0xd};
	for(uint8_t i = 0; i < sizeof(pids); i++)
	{
		obd_comm.pid = pids[i];
		obd2_request(obd_comm);
		if(obd2_request(obd_comm))
		{
			buffer[i][0] = obd_comm.pid;
			buffer[i][1] = obd_comm.current_value;
		}
		else
		{
			buffer[i][0] = buffer_old[i][0];
			buffer[i][1] = buffer_old[i][1];
		}
	}
}

static void create_json(char buff[1000], float array[][2], float array_cpy[][2], int num_of_values)
{
    char json_string [10] = "{\n";
    char temp[100];
    sprintf(buff, json_string);
    for (uint8_t i = 0; i <= num_of_values - 1; i++)
    {
        if(i == num_of_values - 1)
        {
        	sprintf(temp, "\"0x%x\":%.2f}\n", (uint8_t)array[i][0], array[i][1]);
        }
        else
        {
        	sprintf(temp, "\"0x%x\":%.2f,\n", (uint8_t)array[i][0], array[i][1]);
        }
        strcat(buff, temp);
        array_cpy[i][0] = array[i][0];
        array_cpy[i][1] = array[i][1];
    }
}

static void acquire_position(char buff[1000])
{
	if(get_position())
	{
		double lat = pos.latitude;
		double lon = pos.longitude;

		sprintf(buff, "{\"lat\":%f,\"lon\":%f}\n",lat, lon);
	}
}

static uint8_t mqtt_start(BG77 module)
{
	module.mqtt_status = mqtt_open(MQTT_IP,  MQTT_PORT, 0);
	if(module.mqtt_status != 0)
	{
		return (FALSE);
	}
	HAL_Delay(10000);
	if(mqtt_connect(0,"obd10h", &module))
	{
		return (TRUE);
	}
	return (TRUE);
}

static uint8_t mqtt_stop(BG77 module)
{
	if(mqtt_disconnect(0))
	{
		if(mqtt_close(0, module))
		{
			return (FALSE);
		}
		else
		{
			return (TRUE);
		}
	}
	else
	{
		return (TRUE);
	}
}

static float measure_avg_voltage(uint16_t *data)
{
	float result = 0;
	for(int i = 0; i < sizeof(data); i++)
	{
		result += data[i];
	}
	result = result / sizeof(data);
	result = result * (3.3 / 4095);
	result = (result * (100 + 27)) / 27;
	result = roundf(result*100) / 100;
	return result;
}

/* USER CODE END 0 */

/**
  * @brief  The application entry point.
  * @retval int
  */
int main(void)
{
  /* USER CODE BEGIN 1 */
	float obd_buf[99][2];
	float obd_buf_cpy[99][2];
	char buffer[1000];
	char gnss_buffer[1000];
	uint16_t adc_buffer[64] = {0};
	uint32_t timer = 0;
	uint32_t timer_adc = 0;

  /* USER CODE END 1 */

  /* MCU Configuration--------------------------------------------------------*/

  /* Reset of all peripherals, Initializes the Flash interface and the Systick. */
  HAL_Init();

  /* Configure the system clock */
  SystemClock_Config();

  /* Initialize all configured peripherals */
  MX_GPIO_Init();
  MX_DMA_Init();
  MX_ADC1_Init();
  MX_USART1_UART_Init();
  MX_USART2_UART_Init();
  MX_TIM6_Init();
  MX_TIM7_Init();
  MX_TIM16_Init();
  /* USER CODE BEGIN 2 */
//  HAL_ADCEx_Calibration_Start(&hadc1, ADC_SINGLE_ENDED);
//  HAL_ADC_Start_DMA(&hadc1, adc_buffer, 64);

//  obd_comm.voltage = measure_avg_voltage(adc_buffer);

//  while(obd_comm.voltage <= 12.75)
//  {
//	  if((HAL_GetTick() - timer_adc) >= ADC_SAMPLE_TIME)
//	  {
//		  obd_comm.voltage = measure_avg_voltage(adc_buffer);
//		  timer_adc = HAL_GetTick();
//	  }
//  }

  while(!module.initialized)
  {
	  module.initialized = module_init(&module);
  }

//  module.gps = gnss_turn_on();
//  while(!module.gps)
//  {
//
//  }

  obd_comm.used_protocol = obd2_init();

  acquire_vehicle_data(obd_buf, obd_buf_cpy);

  create_json(buffer, obd_buf, obd_buf_cpy,3);

  if(module.gps)
  {
	  acquire_position(gnss_buffer);
  }

  send_command("AT+QGPS=0\r\n","OK", DEFAULT_TIMEOUT, NB);

  module.connected = mqtt_start(module);

//  while(!module.connected)
//  {
//
//  }

  mqtt_publish(0,0,0,0,OBD_TOPIC, buffer);

  if(module.gps)
  {
	  mqtt_publish(0,0,0,0,GPS_TOPIC, gnss_buffer);
  }

  /* USER CODE END 2 */

  /* Infinite loop */
  /* USER CODE BEGIN WHILE */
  while (1)
  {
	  if((HAL_GetTick() - timer) >= 5000)
	  {
		  acquire_vehicle_data(obd_buf, obd_buf_cpy);
		  create_json(buffer, obd_buf, obd_buf_cpy,3);
		  mqtt_publish(0,0,0,0,OBD_TOPIC, buffer);
		  if(module.gps)
		  {
			  acquire_position(gnss_buffer);
			  mqtt_publish(0,0,0,0,GPS_TOPIC, gnss_buffer);
		  }
//		  obd_comm.voltage = measure_avg_voltagee_avg_voltage(adc_buffer);
		  timer = HAL_GetTick();
	  }
//	  if(obd_comm.voltage >= 12.75)
//	  {
//		  mqtt_stop(module);
//
//	  }
    /* USER CODE END WHILE */

    /* USER CODE BEGIN 3 */
  }
  /* USER CODE END 3 */
}

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
/* USER CODE BEGIN 4 */

//uint32_t HAL_GetTick(void)
//{
//	return TIM2->CNT;
//}

/* USER CODE END 4 */
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


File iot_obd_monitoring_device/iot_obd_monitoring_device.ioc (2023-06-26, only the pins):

Mcu.UserName=STM32L431RCTx
PA0.GPIO_Label=IoT_CTS
PA0.Signal=USART2_CTS
PA1.GPIO_Label=IoT_RTS
PA1.Signal=USART2_RTS
PA12.GPIO_Label=L_Line
PA12.Signal=GPIO_Output
PA2.GPIO_Label=IoT_TX
PA2.Signal=USART2_TX
PA3.GPIO_Label=IoT_RX
PA3.Signal=USART2_RX
PA4.GPIO_Label=IoT_RI
PA4.Signal=GPIO_Input
PA5.GPIO_Label=IoT_PWR
PA5.Signal=GPIO_Output
PA6.GPIO_Label=IoT_DTR
PA6.Signal=GPIO_Input
PB6.GPIO_Label=K_Line_TX
PB6.Signal=USART1_TX
PB7.GPIO_Label=K_Line_RX
PB7.Signal=USART1_RX
PB8.Signal=CAN1_RX
PB9.Signal=CAN1_TX
PC2.GPIO_Label=AP_READY
PC2.Signal=GPIO_Output
PC3.GPIO_Label=PON_TRIG
PC3.Signal=GPIO_Output
PC5.GPIO_Label=BAT_V
PC5.Signal=ADCx_IN14
PD2.GPIO_Label=CAN_S
PD2.Signal=GPIO_Output

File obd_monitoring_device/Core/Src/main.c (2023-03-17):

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
/* Includes ------------------------------------------------------------------*/
#include "main.h"

ADC_HandleTypeDef hadc1;
DMA_HandleTypeDef hdma_adc1;

CAN_HandleTypeDef hcan1;

I2C_HandleTypeDef hi2c2;

IWDG_HandleTypeDef hiwdg;

TIM_HandleTypeDef htim1;
TIM_HandleTypeDef htim6;

UART_HandleTypeDef huart1;
DMA_HandleTypeDef hdma_usart1_rx;

/* USER CODE BEGIN PV */

uint8_t uartBuf[10] = {0};

uint16_t adc_buffer[64];

OBD obd_comm;

/* USER CODE END PV */

void SystemClock_Config(void);
static void MX_GPIO_Init(void);
static void MX_DMA_Init(void);;
static void MX_I2C2_Init(void);
static void MX_IWDG_Init(void);
static void MX_TIM1_Init(void);
static void MX_ADC1_Init(void);
static void MX_TIM6_Init(void);
/* USER CODE BEGIN PFP */
static float ADC_Average(uint16_t *data);

/* USER CODE END PFP */

/**
  * @brief  The application entry point.
  * @retval int
  */
int main(void)
{
  /* USER CODE BEGIN 1 */
	uint32_t timer_adc = 0;

  /* USER CODE END 1 */

  /* MCU Configuration--------------------------------------------------------*/

  /* Reset of all peripherals, Initializes the Flash interface and the Systick. */
  HAL_Init();

  /* Configure the system clock */
  SystemClock_Config();

  /* Initialize all configured peripherals */
  MX_GPIO_Init();
  MX_DMA_Init();
  MX_I2C2_Init();
  MX_TIM1_Init();
  MX_ADC1_Init();
  MX_TIM6_Init();
  /* USER CODE BEGIN 2 */

  ssd1306_Init();
  ssd1306_Fill(Black);
  ssd1306_SetCursor(28, 0);
  ssd1306_WriteString("Initialization", Font_7x10, White);
  ssd1306_UpdateScreen();

  HAL_ADCEx_Calibration_Start(&hadc1, ADC_SINGLE_ENDED);
  HAL_ADC_Start_DMA(&hadc1, adc_buffer, 64);

    while(obd_comm.voltage <= 12.75)
    {
  	  if((HAL_GetTick() - timer_adc) >= ADC_SAMPLE_TIME)
  	  {
  		  obd_comm.voltage = ADC_Average(adc_buffer);
  		  timer_adc = HAL_GetTick();
  	  }
  	  if(ssd1306_GetDisplayOn())
  	  {
  		 ssd1306_SetDisplayOn(0);
  	  }
    }

    ssd1306_SetDisplayOn(1);

    timer_adc = 0;

  obd_comm.button_state = 1;

  obd_comm.used_protocol = OBD2_Init();

  obd_comm.pid = 0x05;

  MX_IWDG_Init();

  OBD2_Request(obd_comm);

  OBD2_Request(obd_comm);

  OBD2_Request(obd_comm);

  /* USER CODE END 2 */

  /* Infinite loop */
  /* USER CODE BEGIN WHILE */
  while (1)
  {
	  if((HAL_GetTick() - timer_adc) >= ADC_SAMPLE_TIME)
	  {
		  obd_comm.voltage = ADC_Average(adc_buffer);
		  timer_adc = HAL_GetTick();
	  }
    /* USER CODE END WHILE */

    /* USER CODE BEGIN 3 */
	  if(obd_comm.voltage >= 12.75)
	  {
		  OBD2_Request(obd_comm);
	  }
  }
  /* USER CODE END 3 */
}

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
/* USER CODE BEGIN 4 */
static float ADC_Average(uint16_t *data)
{
	float result = 0;
	for(int i = 0; i < sizeof(data); i++)
	{
		result += data[i];
	}
	result = result / sizeof(data);
	result = result * (3.3 / 4095);
	result = (result * (100 + 27)) / 27;
	result = roundf(result*100) / 100;
	return result;
}

/* USER CODE END 4 */
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


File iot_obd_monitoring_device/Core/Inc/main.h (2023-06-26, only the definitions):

#define HSE_IN_Pin GPIO_PIN_0
#define HSE_IN_GPIO_Port GPIOH
#define HSE_OUT_Pin GPIO_PIN_1
#define HSE_OUT_GPIO_Port GPIOH
#define AP_READY_Pin GPIO_PIN_2
#define AP_READY_GPIO_Port GPIOC
#define PON_TRIG_Pin GPIO_PIN_3
#define PON_TRIG_GPIO_Port GPIOC
#define IoT_CTS_Pin GPIO_PIN_0
#define IoT_CTS_GPIO_Port GPIOA
#define IoT_RTS_Pin GPIO_PIN_1
#define IoT_RTS_GPIO_Port GPIOA
#define IoT_TX_Pin GPIO_PIN_2
#define IoT_TX_GPIO_Port GPIOA
#define IoT_RX_Pin GPIO_PIN_3
#define IoT_RX_GPIO_Port GPIOA
#define IoT_RI_Pin GPIO_PIN_4
#define IoT_RI_GPIO_Port GPIOA
#define IoT_PWR_Pin GPIO_PIN_5
#define IoT_PWR_GPIO_Port GPIOA
#define IoT_DTR_Pin GPIO_PIN_6
#define IoT_DTR_GPIO_Port GPIOA
#define BAT_V_Pin GPIO_PIN_5
#define BAT_V_GPIO_Port GPIOC
#define L_Line_Pin GPIO_PIN_12
#define L_Line_GPIO_Port GPIOA
#define SWDIO_Pin GPIO_PIN_13
#define SWDIO_GPIO_Port GPIOA
#define SWCLK_Pin GPIO_PIN_14
#define SWCLK_GPIO_Port GPIOA
#define CAN_S_Pin GPIO_PIN_2
#define CAN_S_GPIO_Port GPIOD
#define SWO_Pin GPIO_PIN_3
#define SWO_GPIO_Port GPIOB
#define K_Line_TX_Pin GPIO_PIN_6
#define K_Line_TX_GPIO_Port GPIOB
#define K_Line_RX_Pin GPIO_PIN_7
#define K_Line_RX_GPIO_Port GPIOB
#define TRUE 1
#define FALSE 0
#define MQTT_IP "147.229.148.103"
#define MQTT_PORT 1883
#define OBD_TOPIC "topic/obd"
#define GPS_TOPIC "topic/gps"
#define ADC_SAMPLE_TIME 1000

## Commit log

2022-10-25 Board v2 - reduced size
    [BOM-stm_v3.csv, connectors.kicad_sch, power_supply.kicad_sch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]
2022-10-27 Further board size reduction
    [BOM-stm_v3.csv, connectors.kicad_sch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]
2022-11-01 Final board version
    [POS-stm_v3.csv, stm_v3-CuBottom.gbr, stm_v3-CuIn1.gbr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]
2022-11-07 CAN Bus communication implemented
2022-11-24 24/11/22 update
    [stm_v3.kicad_sch]
2022-11-28 Update 28/11/22 CAN BUS - implemented, K Line - WIP, OLED implemented
2023-01-21 KLine update 21/01/23
    [connectors.kicad_sch, stm_v3.kicad_sch]
2023-01-25 Repo cleanup - 2.0
    [connectors.kicad_sch, power_supply.kicad_sch, stm_v3.kicad_pcb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]
2023-01-29 Case update 29/01/23
    [Asm2.cfg]
2023-02-02 Case update 02/02/23
    [Asm3.cfg, Asm6.cfg, base.stl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]
2023-02-05 Case update 05/02/23
    [base_v2.stl, top_v2.stl]
2023-02-08 Update 08/02/23 - CAN Bus fixed, Button WIP
    [CAN.c, KLine.c, OBD.c]
2023-02-09 Update 09/02/23 - Button update
2023-02-14 Update 14/02/23 - fixed KWP2000 & button debounce
    [CAN.c, KLine.c, main.c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]
2023-02-18 Update 18/02/23 - added monitoring for battery voltage
2023-02-26 Update 27/02/23 - new schematic
    [bom.csv, car.kicad_sch, connect.kicad_sch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]
2023-03-03 Update 03/03/23 - new schematic done
    [ant.kicad_sch, car.kicad_sch, connect.kicad_sch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]
2023-03-06 Update 06/03/23 - new board layout WIP 70%
    [ant.kicad_sch, car.kicad_sch, connect.kicad_sch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]
2023-03-07 Update 07/03/23 - board layout done
    [ant.kicad_sch, iot.kicad_sch, iot_diagnostic_tool.kicad_pcb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]
2023-03-13 Update 13/03/23 - Board layout fixes
    [ant.kicad_sch, iot_diagnostic_tool.kicad_pcb, sim.kicad_sch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]
2023-03-17 Update 17/03/23 - final board update, generated files for manufacturing
    [BOM-iot_diagnostic_tool.csv, car.kicad_sch, connect.kicad_sch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]
2023-04-01 Update 02/04/23 - BG77 driver WIP
2023-04-24 Update 2 24/04/23 - send_command bug fix
    [bg77.c, usart.c]
2023-04-29 Update 29/04/23 - repaired mqtt_connect & send_command, added comments in the driver
2023-05-05 Update 06/05/23 - added STEP file of the iot board
2023-05-07 Update 07/05/23 - new step file for board
2023-05-08 Update 08/05/23 - new case design
    [436500827.iam, 693023010811.iam, Asm2.cfg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]
2023-05-13 Update 13/05/13 - BG77 driver bug fix
    [KLine.c, OBD.c, bg77.c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]
2023-05-13 Update 14/05/23 - obd functionality bug fix
    [KLine.c, OBD.c, bg77.c]
2023-06-26 Update 26/06/23 - Thesis release
    [2023-05-15_17_08_influxdb_data.csv, 2023-05-21_18_17_influxdb_data.csv, 2023-05-21_18_19_influxdb_data.csv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]

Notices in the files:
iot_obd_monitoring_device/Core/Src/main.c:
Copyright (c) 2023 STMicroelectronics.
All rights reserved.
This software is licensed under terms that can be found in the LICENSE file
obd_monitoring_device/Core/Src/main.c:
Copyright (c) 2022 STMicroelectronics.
